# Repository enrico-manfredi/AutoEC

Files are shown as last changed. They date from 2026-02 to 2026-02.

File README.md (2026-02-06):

# AutoEC

**AutoEC** is an open-source **automated pumping and switching system** designed to support **batch electrochemical testing of electrolytes through membrane electrode assemblies (MEAs)**.

The system was developed to enable reproducible, programmable control of fluid handling during electrochemical experiments, particularly where repeated electrolyte exchange, flow control, and test cycling are required.

This repository contains control software, test scripts, mechanical design assets, and documentation describing the AutoEC prototype platform.

---

## Project objectives

- Automate fluid handling for electrochemical testing
- Enable programmable control of pumps and switching sequences
- Improve repeatability and throughput in batch MEA experiments
- Provide a flexible platform for rapid experimental iteration

---

## System overview

AutoEC integrates:

### Control software
- **Python-based host control scripts** for pump actuation and experiment sequencing
- Modular test scripts used to validate hardware functionality
- A high-level control interface for coordinating fluid handling steps

### Pump control
- Syringe pumps are controlled using the open-source **`runze-control` Python library**, developed by **Allen Institute / AllenNeuralDynamics**
- This library provides the low-level serial communication and command abstraction for Runze syringe pumps

### Mechanical system
- CAD parts and assemblies (`.ipt`, `.iam`) supporting:
  - Syringe pump frames and holders
  - Structural frames and chamber fixtures
  - Z-axis bars and mounting components

---

## Dependencies

AutoEC relies on the following external libraries:

### Required
- **runze-control**  
  Pump control library for Runze syringe pumps  
  Developed and maintained by **AllenNeuralDynamics**  
  https://github.com/AllenNeuralDynamics/runze-control

- **pyserial**  
  Required for serial communication with pump hardware

Install dependencies using:
```bash
pip install pyserial
pip install git+https://github.com/AllenNeuralDynamics/runze-control.git

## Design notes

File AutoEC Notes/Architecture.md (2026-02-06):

![[Pasted image 20240330184920.png]]
## Modules
- Mains power is an extension chord with enough plugs for other the [[Power Supplies]] of connected devices (5) and is connected to a [[Kill Switch]] that allows for the system to be switched off automatically (int22) for safety and sustainability reasons.
- The Control PC is a windows machine that centrally controls the movement and operation of all devices in the system, and is also responsible for monitoring errors or failure conditions. Should be accessible remotely.
- [[Syringe Pump]] is the fluid driving element that retrieves both sample and wash solution and pumps them through the electrochemical cell
- Test solutions are solutions of [[Catholyte]] and [[Anolyte]] that need to be tested, and will be in a [[Sample Rack]] which is easily accessible and interchangeable to the user
- [[Wash Solution]] will be used to purge all elements of the fluid system from any traces of test solutions
- [[Potentiostat]] is the device that controls cell potential and current between the electrodes as well as responsible for taking measurements from the cell and reporting those measurements to the control PC.
- [[Booster]] is a device controlled by the potentiostat via proprietary interface (int13) that increases the amount of current that can be delivered to the cell.
- The [[Cell]] is [[Membrane]] [[Electrode]] assembly (MEA) in which the test solutions travel through a [[Fluid Path]] during electrochemical measurement by the potentiostat.
- Test solution [[Reservoirs]] are chambers where the current test solution will drain into after being pumped through the cell and where the syringe filters will fill from during operation and dispense to when setting up for a new test solution run.
- [[Thermal Control]] is the thermostat system that will heat up the cell and/or syringe pumps and reservoirs to maintain a constant temperature for the liquids being run through the system.

## Interfaces
1. Fluid transfer link between wash solution reservoir and the syringe pump valve selector
2. Fluid transfer link from the syringe pump to a waste container for spent wash solution and/or excess test solutions
3. Fluid transfer link from the test solution reservoir to the syringe pump such that the syringe pump can be loaded with test solution
4. Fluid transfer link from the syringe pump to the test solution reservoir such that the syringe pump can be dispensed into the test solution reservoir (in implementation this would be on the same fluid line as 3 as the syringe pump is bidirectional)
5. A fluid transfer link between the syringe pump and the cell fluid inlet such that the syringe pump can dispense test solution into the cell
6. A fluid transfer link between the cell and the test solution reservoir such that fluid moving through the cell can be drained into the reservoir
7. An electrical communication link from the syringe pump to the control PC shows the control PC the pump status and any errors that the pump has encountered, such as overheating, stalling or blockage
8. An electrical communication link from the control PC to the syringe pump that allows the control PC to send actuation commands to the syringe pump (in implementation this will be a single bidirectional RS-485 connection using the protocol set out in [[Syringe Pump]])
9. A fluid transfer link from a particular test solution in the test solution rack to the syringe pump that allows for test solution to be drawn into the syringe pump
10. A fluid transfer link from the syringe pump to a particular test solution in the test solution rack that allows for the dispensation of test solution from the syringe pump into the appropriate sample container

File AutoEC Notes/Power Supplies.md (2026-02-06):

Control PC, Potentiostat and Thermal control all come with their own mains power supplies.

[[Syringe Pump]] will have their own integrated supply composed of one 24V 10A mains power brick to fit with other elements of the system

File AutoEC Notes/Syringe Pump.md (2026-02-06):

A integrated syringe pump and 6-way selector valve. Usage instructions are provided in the manual below:
[[sy-01b-ascii-code-instruction-manuall-v1-1.pdf]]
## General
- The stepper motor controlling the syringe stroke has 12,000 steps total 
- stroke length of 30mm
- Can take syringes from 25uL to 5mL
- All numbers sent via serial (for example for number of steps) must be sent in hexadecimal
- Recommends using RS232/485 comm protocol as it will send back more checksum and status data than raw terminal commands
- Requires 24V power with minimum 1.5A specification and a maximum operating current of 31A (and limit of 35A)
- Must always be run with liquid else the sealing surfaces can be damaged
- Have a self test mode if address switch is set to position F
## Addressing
![[Pasted image 20240330162039.png]]

## Comm Protocol
![[Pasted image 20240330161352.png]]
For sending data:
- STX is the start string
- Pump address is according to the table in [[Syringe Pump#Addressing]]
- Sequence number -  a number from 0-7 and a bit flag for repetition. Only read if the bit flag is high - used to check whether it is currently repeating the same command as previous or whether (acknowledge only) it is receiving a new command to repeat (acknowledge and execute).
- Data block - the data or command to be sent as an ascii string (see [[Syringe Pump#Commands]])
- ETX is the end of the string
- Checksum is used to check for communication errors or corruptions

For receiving data:
- Master address - the address of the host computer - always set to 30h (0 in ascii)
- Status code - a code that will either indicate pump status (ready/busy) or [[Syringe Pump#Error Codes]]

## Manual Control
Using SerialCommV1.0 provided by Runze it is possible to operate a single pump directly from the terminal by sending and receiving serial commands. This software only works with windows.
Other settings:
- Only 9600 Brate supported (other params same as [[Syringe Pump#Comm Protocol]])
- Pump address switch must be set to 0.
## Commands
### General
Commands are stored in a 255 char buffer. A single R at the end of the command string indicates that the command is to be run immediately, otherwise it will enter the buffer and be kept there until a new command is received where the buffer will be overwritten. The pump will not accept further commands unless the current command has been completed (hence don't send until confirmation of complete command from the pump - can maybe also place in buffer?). If the command receives an incorrect command it will send an error code back to the host computer.

#### Backlash Config
Kn where n is between 0-800 for full steps and 0-1600 in microstepping mode (fine positioning which does halg steps)

#### Pump Config
Un where n can take the following values:
![[Pasted image 20240330174535.png]]
The pump must be restarted for these to take effect.

The U200 commands are presumably in the form of U201 for a 1A stall current and U231 for a 31A stall current (to be tested)
- Stall current must be set to be below the maximum rated current of the power supply being used

#### Initialisation
The plunger and valve drive can be initialised seperately or together and going counter clockwise Y(n1, n2, n3) or clockwise Z(n1, n2, n3) - presumably the sub blocks use commas as separators

For combined plunger and valve initialisation, the table of values is shown below:
![[Pasted image 20240330175514.png]]
## Error Codes

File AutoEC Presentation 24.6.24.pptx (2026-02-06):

## Current Setup

Wash

Waste

Control PC

Wash

Waste

3

4

Anode Samples

Potentiostat

1

2

Anode
Pumps

Temp
Control

Cathode
Pumps

Anolyte
Chamber

Catholyte
Chamber

Cathode Samples

## Current Spec

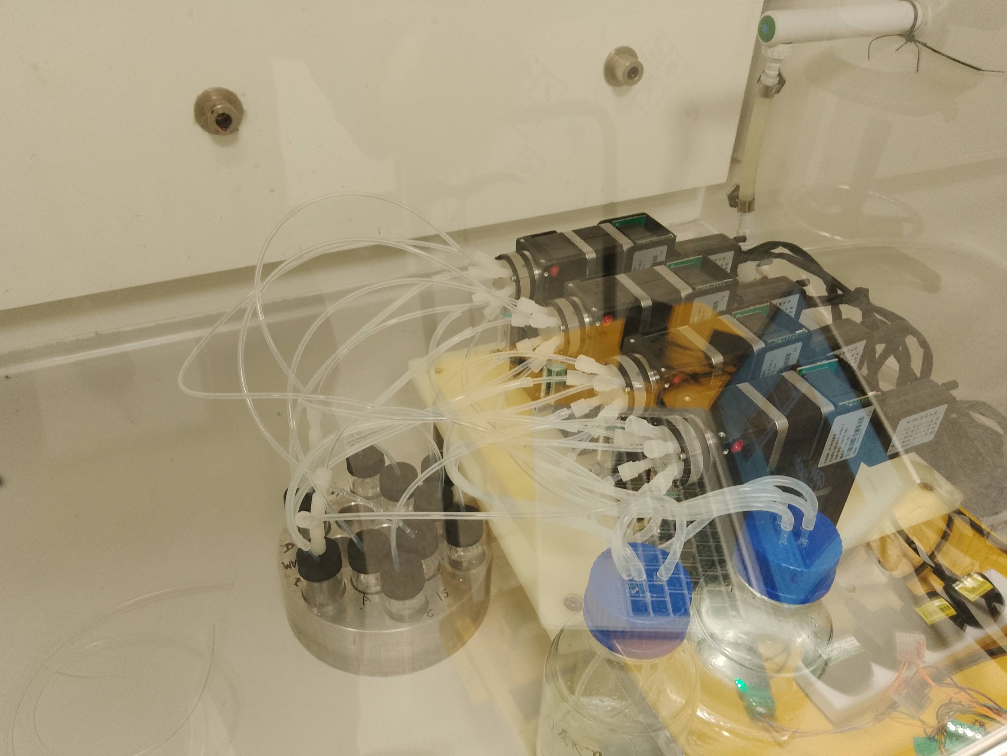
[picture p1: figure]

- Addressable samples for each run
  - E.g. [1,2] means 1st sample on anode and 2nd sample on cathode
  - Returns samples to original pot after testing (15ml)
- System runs on ivium potentiostat
  - Runs off saved methods from ivsoft
- Cleaning functions integrated at the end of every run
  - Membrane
  - Chamber
  - Syringes
- Manual temperature control – all experiments in one batch (4 pairs) must be run at one temp
- Currently based in Chem831 for prototyping & testing

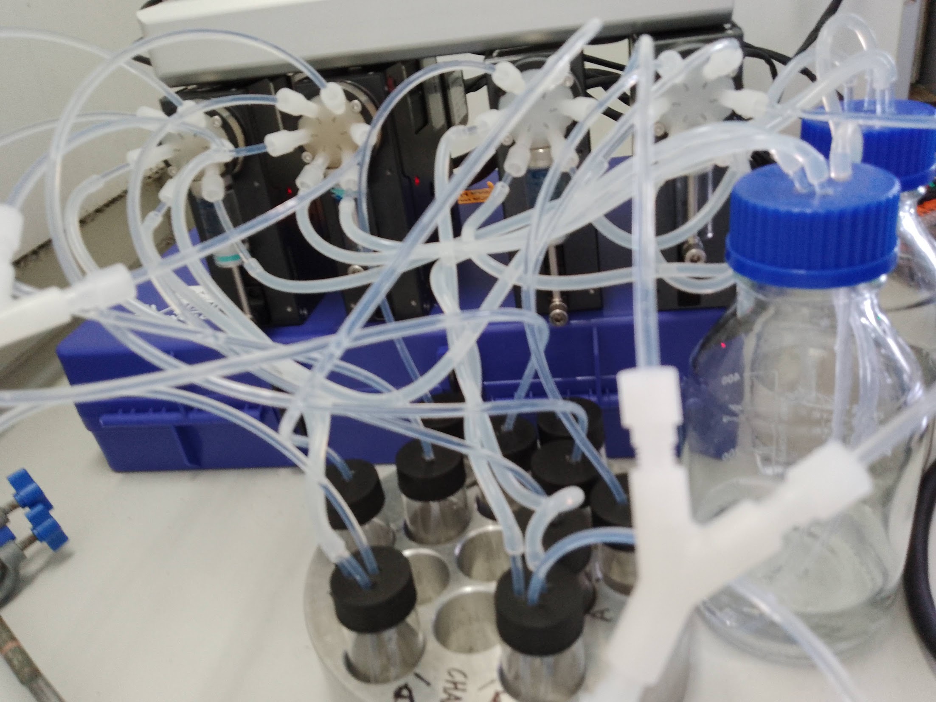
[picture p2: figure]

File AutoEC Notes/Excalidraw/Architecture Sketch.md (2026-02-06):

---

excalidraw-plugin: parsed
tags: [excalidraw]

---
==⚠  Switch to EXCALIDRAW VIEW in the MORE OPTIONS menu of this document. ⚠==

# Text Elements
Cell ^l1ibORYI

Test Solution Reservoirs ^jnntJJiP

Potentiostat ^KO1CpPYg

Booster ^whiRIF5I

Syringe Pump ^FSPLhmo9

Test Solutions ^VonvnywQ

Control PC ^r2QTvRRM

Wash Solution ^82Awlkmj

1 ^7IcscnHT

2 ^HzHET0HD

3 ^dt2o3Fhl

4 ^zDjwsGoj

5 ^eu0UEI3d

6 ^kACNqNml

7 ^nSBoxbeC

8 ^qrnZnVmD

9 ^oPMFp0x9

10 ^uov3VFLc

11 ^4vQkV3Ot

12 ^VfAVOvvz

13 ^rdQFTPa8

14 ^UYDHrkcZ

15 ^f7A9KPbZ

Thermal Control ^VKspB7Ql

16 ^eN7tv0N0

24 ^S0jkShm5

25 ^kDEbEBqd

19 ^sT7MlVia

17 ^4mHRUdfI

Mains Power ^oH1eUweU

18 ^sdlnf21B

19 ^9JnUwH7v

20 ^PlxXwrGl

21 ^o0szQ5ke

22 ^zDNTCGsT

23 ^8Dt4diBY

%%
# Drawing
```json
{
	"type": "excalidraw",
	"version": 2,
	"source": "https://github.com/zsviczian/obsidian-excalidraw-plugin/releases/tag/2.0.26",
	"elements": [
		{
			"type": "rectangle",
			"version": 182,
			"versionNonce": 1813121673,
			"isDeleted": false,
			"id": "bU9Jms2O_zU1_lSFDH0oY",
			"fillStyle": "solid",
			"strokeWidth": 2,
			"strokeStyle": "solid",
			"roughness": 1,
			"opacity": 100,
			"angle": 0,
			"x": -9.6666259765625,
			"y": -386.7864532470703,
			"strokeColor": "#1e1e1e",
			"backgroundColor": "transparent",
			"width": 86.666748046875,
			"height": 57.3333740234375,
			"seed": 99178377,
			"groupIds": [],
			"frameId": null,
			"roundness": {
				"type": 3
			},
			"boundElements": [
				{
					"type": "text",
					"id": "l1ibORYI"
				},
				{
					"id": "BvJilRcO0jTmNDnqUFmX5",
					"type": "arrow"
				},
				{
					"id": "ODdBEutdLjqXaOnD44ZyQ",
					"type": "arrow"
				},
				{
					"id": "G5-fBYSrN0bbWU4KgB2QC",
					"type": "arrow"
				},
				{
					"id": "1mDEJUfH4Xlski9YfvWLL",
					"type": "arrow"
				},
				{
					"id": "Q9TIKDFtSWsWlMSElXdRT",
					"type": "arrow"
				}
			],
			"updated": 1711823752772,
			"link": null,
			"locked": false
		},
		{
			"type": "text",
			"version": 159,
			"versionNonce": 1463967209,
			"isDeleted": false,
			"id": "l1ibORYI",
			"fillStyle": "solid",
			"strokeWidth": 2,
			"strokeStyle": "solid",
			"roughness": 1,
			"opacity": 100,
			"angle": 0,
			"x": 16.49676513671875,
			"y": -370.61976623535156,
			"strokeColor": "#1e1e1e",
			"backgroundColor": "transparent",
			"width": 34.3399658203125,
			"height": 25,
			"seed": 1843980713,
			"groupIds": [],
			"frameId": null,
			"roundness": null,
			"boundElements": [],
			"updated": 1711823525700,
			"link": null,
			"locked": false,
			"fontSize": 20,
			"fontFamily": 1,
			"text": "Cell",
			"rawText": "Cell",
			"textAlign": "center",
			"verticalAlign": "middle",
			"containerId": "bU9Jms2O_zU1_lSFDH0oY",
			"originalText": "Cell",
			"lineHeight": 1.25
		},
		{
			"type": "rectangle",
			"version": 694,
			"versionNonce": 569758023,
			"isDeleted": false,
			"id": "ODWRP1MtLcp3Vh7PsQYtS",
			"fillStyle": "solid",
			"strokeWidth": 2,
			"strokeStyle": "solid",
			"roughness": 1,
			"opacity": 100,
			"angle": 0,
			"x": -50.66680908203125,
			"y": -570.7864990234375,
			"strokeColor": "#1e1e1e",
			"backgroundColor": "transparent",
			"width": 162.00006103515622,
			"height": 71,
			"seed": 1713174183,
			"groupIds": [],
			"frameId": null,
			"roundness": {
				"type": 3
			},
			"boundElements": [
				{
					"type": "text",
					"id": "jnntJJiP"
				},
				{
					"id": "bC6mpMbLD5vmOgMO0ALFV",
					"type": "arrow"
				},
				{
					"id": "BvJilRcO0jTmNDnqUFmX5",
					"type": "arrow"
				},
				{
					"id": "ODdBEutdLjqXaOnD44ZyQ",
					"type": "arrow"
				},
				{
					"id": "aO0yKPbcSyfrLUch1YeXE",
					"type": "arrow"
				},
				{
					"id": "nsKn9Tmc4jUIkaFDwNtvG",
					"type": "arrow"
				}
			],
			"updated": 1711823757336,
			"link": null,
			"locked": false
		},
		{
			"type": "text",
			"version": 708,
			"versionNonce": 1259805481,
			"isDeleted": false,
			"id": "jnntJJiP",
			"fillStyle": "solid",
			"strokeWidth": 2,
			"strokeStyle": "solid",
			"roughness": 1,
			"opacity": 100,
			"angle": 0,
			"x": -37.23670959472658,
			"y": -560.2864990234375,
			"strokeColor": "#1e1e1e",
			"backgroundColor": "transparent",
			"width": 135.13986206054688,
			"height": 50,
			"seed": 1555401159,
			"groupIds": [],
			"frameId": null,
			"roundness": null,
			"boundElements": [],
			"updated": 1711823525700,
			"link": null,
			"locked": false,
			"fontSize": 20,
			"fontFamily": 1,
			"text": "Test Solution\nReservoirs",
			"rawText": "Test Solution Reservoirs",
			"textAlign": "center",
			"verticalAlign": "middle",
			"containerId": "ODWRP1MtLcp3Vh7PsQYtS",
			"originalText": "Test Solution Reservoirs",
			"lineHeight": 1.25
		},
		{
			"type": "rectangle",
			"version": 263,
			"versionNonce": 107527369,
			"isDeleted": false,
			"id": "3vFeRiSeK2OI2f1WuSYI6",
			"fillStyle": "solid",
			"strokeWidth": 2,
			"strokeStyle": "solid",
			"roughness": 1,
			"opacity": 100,
			"angle": 0,
			"x": 19.00006103515625,
			"y": -128.7863311767578,
			"strokeColor": "#1e1e1e",
			"backgroundColor": "transparent",
			"width": 147.99993896484375,
			"height": 64.00000000000001,
			"seed": 596154183,
			"groupIds": [],
			"frameId": null,
			"roundness": {
				"type": 3
			},
			"boundElements": [
				{
					"type": "text",
					"id": "KO1CpPYg"
				},
				{
					"id": "vgSNt6wNqVpfVCbIR9f1w",
					"type": "arrow"
				},
				{
					"id": "1mDEJUfH4Xlski9YfvWLL",
					"type": "arrow"
				},
				{
					"id": "WnmydR_rrgiI1EIDTvmJa",
					"type": "arrow"
				},
				{
					"id": "8TptVns8V0LvRrpCr_jtZ",
					"type": "arrow"
				},
				{
					"id": "TLeKdNhl8hJ3KNtLr0rVx",
					"type": "arrow"
				}
			],
			"updated": 1711824281116,
			"link": null,
			"locked": false
		},
		{
			"type": "text",
			"version": 239,
			"versionNonce": 1947002985,
			"isDeleted": false,
			"id": "KO1CpPYg",
			"fillStyle": "solid",
			"strokeWidth": 2,
			"strokeStyle": "solid",
			"roughness": 1,
			"opacity": 100,
			"angle": 0,
			"x": 28.28009796142578,
			"y": -109.28633117675781,
			"strokeColor": "#1e1e1e",
			"backgroundColor": "transparent",
			"width": 129.4398651123047,
			"height": 25,
			"seed": 373793639,
			"groupIds": [],
			"frameId": null,
			"roundness": null,
			"boundElements": [],
			"updated": 1711823525700,
			"link": null,
			"locked": false,
			"fontSize": 20,
			"fontFamily": 1,
			"text": "Potentiostat",
			"rawText": "Potentiostat",
			"textAlign": "center",
			"verticalAlign": "middle",
			"containerId": "3vFeRiSeK2OI2f1WuSYI6",
			"originalText": "Potentiostat",
			"lineHeight": 1.25
		},
		{
			"type": "rectangle",
			"version": 424,
			"versionNonce": 1791202121,
			"isDeleted": false,
			"id": "dKkvgd4W00acrC5qZFvRn",
			"fillStyle": "solid",
			"strokeWidth": 2,
			"strokeStyle": "solid",
			"roughness": 1,
			"opacity": 100,
			"angle": 0,
			"x": 17.333343505859375,
			"y": -251.4530792236328,
			"strokeColor": "#1e1e1e",
			"backgroundColor": "transparent",
			"width": 115.333251953125,
			"height": 50.666687011718736,
			"seed": 936432327,
			"groupIds": [],
			"frameId": null,
			"roundness": {
				"type": 3
			},
			"boundElements": [
				{
					"type": "text",
					"id": "whiRIF5I"
				},
				{
					"id": "G5-fBYSrN0bbWU4KgB2QC",
					"type": "arrow"
				},
				{
					"id": "vgSNt6wNqVpfVCbIR9f1w",
					"type": "arrow"
				},
				{
					"id": "cscG2V1hwLWiyM6O2XQi9",
					"type": "arrow"
				}
			],
			"updated": 1711824287372,
			"link": null,
			"locked": false
		},
		{
			"type": "text",
			"version": 409,
			"versionNonce": 1779942825,
			"isDeleted": false,
			"id": "whiRIF5I",
			"fillStyle": "solid",
			"strokeWidth": 2,
			"strokeStyle": "solid",
			"roughness": 1,
			"opacity": 100,
			"angle": 0,
			"x": 35.800010681152344,
			"y": -238.61973571777344,
			"strokeColor": "#1e1e1e",
			"backgroundColor": "transparent",
			"width": 78.39991760253906,
			"height": 25,
			"seed": 1608049127,
			"groupIds": [],
			"frameId": null,
			"roundness": null,
			"boundElements": [],
			"updated": 1711823525700,
			"link": null,
			"locked": false,
			"fontSize": 20,
			"fontFamily": 1,
			"text": "Booster",
			"rawText": "Booster",
			"textAlign": "center",
			"verticalAlign": "middle",
			"containerId": "dKkvgd4W00acrC5qZFvRn",
			"originalText": "Booster",
			"lineHeight": 1.25
		},
		{
			"type": "rectangle",
			"version": 522,
			"versionNonce": 1964805415,
			"isDeleted": false,
			"id": "0TH1Q8r3-1oxOPPtuFwd4",
			"fillStyle": "solid",
			"strokeWidth": 2,
			"strokeStyle": "solid",
			"roughness": 1,
			"opacity": 100,
			"angle": 0,
			"x": -185.99993896484375,
			"y": -399.11985778808594,
			"strokeColor": "#1e1e1e",
			"backgroundColor": "transparent",
			"width": 102.6666259765625,
			"height": 60,
			"seed": 1482070887,
			"groupIds": [],
			"frameId": null,
			"roundness": {
				"type": 3
			},
			"boundElements": [
				{
					"type": "text",
					"id": "FSPLhmo9"
				},
				{
					"id": "enI0Gv2CJua86-YhZFvDU",
					"type": "arrow"
				},
				{
					"id": "bC6mpMbLD5vmOgMO0ALFV",
					"type": "arrow"
				},
				{
					"id": "DohW-taXoE-uIEI_2FnnT",
					"type": "arrow"
				},
				{
					"id": "wcmA01sqSDBKsLx3GLCXA",
					"type": "arrow"
				},
				{
					"id": "poeBGR7nkOoXHoHTLJWXH",
					"type": "arrow"
				},
				{
					"id": "aO0yKPbcSyfrLUch1YeXE",
					"type": "arrow"
				},
				{
					"id": "uCttJyokoXdWlUvNB0RQG",
					"type": "arrow"
				},
				{
					"id": "5Zj_0U34enpYEs7bhw5o1",
					"type": "arrow"
				},
				{
					"id": "YjDV_4WW3z9hB24ijSn9G",
					"type": "arrow"
				},
				{
					"id": "GrVChs8RONhCqfv4I8e7B",
					"type": "arrow"
				},
				{
					"id": "BvJilRcO0jTmNDnqUFmX5",
					"type": "arrow"
				}
			],
			"updated": 1712074583495,
			"link": null,
			"locked": false
		},
		{
			"type": "text",
			"version": 484,
			"versionNonce": 208087337,
			"isDeleted": false,
			"id": "FSPLhmo9",
			"fillStyle": "solid",
			"strokeWidth": 2,
			"strokeStyle": "solid",
			"roughness": 1,
			"opacity": 100,
			"angle": 0,
			"x": -167.07659149169922,
			"y": -394.11985778808594,
			"strokeColor": "#1e1e1e",
			"backgroundColor": "transparent",
			"width": 64.81993103027344,
			"height": 50,
			"seed": 1239193223,
			"groupIds": [],
			"frameId": null,
			"roundness": null,
			"boundElements": [],
			"updated": 1711823525700,
			"link": null,
			"locked": false,
			"fontSize": 20,
			"fontFamily": 1,
			"text": "Syringe\nPump",
			"rawText": "Syringe Pump",
			"textAlign": "center",
			"verticalAlign": "middle",
			"containerId": "0TH1Q8r3-1oxOPPtuFwd4",
			"originalText": "Syringe Pump",
			"lineHeight": 1.25
		},
		{
			"type": "rectangle",
			"version": 726,
			"versionNonce": 1527309607,
			"isDeleted": false,
			"id": "JYXKch51sxRrdpWpH71tc",
			"fillStyle": "solid",
			"strokeWidth": 2,
			"strokeStyle": "solid",
			"roughness": 1,
			"opacity": 100,
			"angle": 0,
			"x": -191.2701497085289,
			"y": -217.37008729779745,
			"strokeColor": "#1e1e1e",
			"backgroundColor": "transparent",
			"width": 102.6666259765625,
			"height": 60,
			"seed": 1685218025,
			"groupIds": [],
			"frameId": null,
			"roundness": {
				"type": 3
			},
			"boundElements": [
				{
					"type": "text",
					"id": "VonvnywQ"
				},
				{
					"id": "enI0Gv2CJua86-YhZFvDU",
					"type": "arrow"
				},
				{
					"id": "DohW-taXoE-uIEI_2FnnT",
					"type": "arrow"
				}
			],
			"updated": 1711824239220,
			"link": null,
			"locked": false
		},
		{
			"type": "text",
			"version": 720,
			"versionNonce": 1528801351,
			"isDeleted": false,
			"id": "VonvnywQ",
			"fillStyle": "solid",
			"strokeWidth": 2,
			"strokeStyle": "solid",
			"roughness": 1,
			"opacity": 100,
			"angle": 0,
			"x": -183.3467869765953,
			"y": -212.37008729779745,
			"strokeColor": "#1e1e1e",
			"backgroundColor": "transparent",
			"width": 86.81990051269531,
			"height": 50,
			"seed": 332930505,
			"groupIds": [],
			"frameId": null,
			"roundness": null,
			"boundElements": [],
			"updated": 1711824239220,
			"link": null,
			"locked": false,
			"fontSize": 20,
			"fontFamily": 1,
			"text": "Test\nSolutions",
			"rawText": "Test Solutions",
			"textAlign": "center",
			"verticalAlign": "middle",
			"containerId": "JYXKch51sxRrdpWpH71tc",
			"originalText": "Test Solutions",
			"lineHeight": 1.25
		},
		{
			"type": "arrow",
			"version": 692,
			"versionNonce": 1043069351,
			"isDeleted": false,
			"id": "enI0Gv2CJua86-YhZFvDU",
			"fillStyle": "solid",
			"strokeWidth": 2,
			"strokeStyle": "solid",
			"roughness": 1,
			"opacity": 100,
			"angle": 0,
			"x": -173.57272661146584,
			"y": -229.70346132123495,
			"strokeColor": "#1e1e1e",
			"backgroundColor": "transparent",
			"width": 2.8383024337055645,
			"height": 96.41636594927286,
			"seed": 1249848263,
			"groupIds": [],
			"frameId": null,
			"roundness": {
				"type": 2
			},
			"boundElements": [
				{
					"type": "text",
					"id": "oPMFp0x9"
				}
			],
			"updated": 1712073796478,
			"link": null,
			"locked": false,
			"startBinding": {
				"elementId": "JYXKch51sxRrdpWpH71tc",
				"gap": 12.3333740234375,
				"focus": -0.6680288907144092
			},
			"endBinding": {
				"elementId": "0TH1Q8r3-1oxOPPtuFwd4",
				"gap": 13.000030517578125,
				"focus": 0.6664942364970273
			},
			"lastCommittedPoint": null,
			"startArrowhead": null,
			"endArrowhead": "arrow",
			"points": [
				[
					0,
					0
				],
				[
					2.8383024337055645,
					-96.41636594927286
				]
			]
		},
		{
			"type": "text",
			"version": 2,
			"versionNonce": 2005278887,
			"isDeleted": false,
			"id": "oPMFp0x9",
			"fillStyle": "solid",
			"strokeWidth": 2,
			"strokeStyle": "solid",
			"roughness": 1,
			"opacity": 100,
			"angle": 0,
			"x": -183.53589980463613,
			"y": 102.71350097656251,
			"strokeColor": "#1e1e1e",
			"backgroundColor": "transparent",
			"width": 12.17999267578125,
			"height": 25,
			"seed": 6941865,
			"groupIds": [],
			"frameId": null,
			"roundness": null,
			"boundElements": [],
			"updated": 1711823453330,
			"link": null,
			"locked": false,
			"fontSize": 20,
			"fontFamily": 1,
			"text": "9",
			"rawText": "9",
			"textAlign": "center",
			"verticalAlign": "middle",
			"containerId": "enI0Gv2CJua86-YhZFvDU",
			"originalText": "9",
			"lineHeight": 1.25
		},
		{
			"type": "arrow",
			"version": 325,
			"versionNonce": 250289191,
			"isDeleted": false,
			"id": "bC6mpMbLD5vmOgMO0ALFV",
			"fillStyle": "solid",
			"strokeWidth": 2,
			"strokeStyle": "solid",
			"roughness": 1,
			"opacity": 100,
			"angle": 0,
			"x": -79,
			"y": -386.68933894139536,
			"strokeColor": "#1e1e1e",
			"backgroundColor": "transparent",
			"width": 71.34436332718883,
			"height": 108.7638013173937,
			"seed": 1119397577,
			"groupIds": [],
			"frameId": null,
			"roundness": {
				"type": 2
			},
			"boundElements": [
				{
					"type": "text",
					"id": "zDjwsGoj"
				}
			],
			"updated": 1712073796467,
			"link": null,
			"locked": false,
			"startBinding": {
				"elementId": "0TH1Q8r3-1oxOPPtuFwd4",
				"gap": 4.33331298828125,
				"focus": 0.6216103198222338
			},
			"endBinding": {
				"elementId": "ODWRP1MtLcp3Vh7PsQYtS",
				"gap": 4.3333587646484375,
				"focus": 0.11372414050710765
			},
			"lastCommittedPoint": null,
			"startArrowhead": null,
			"endArrowhead": "arrow",
			"points": [
				[
					0,
					0
				],
				[
					71.34436332718883,
					-108.7638013173937
				]
			]
		},
		{
			"type": "text",
			"version": 2,
			"versionNonce": 680751625,
			"isDeleted": false,
			"id": "zDjwsGoj",
			"fillStyle": "solid",
			"strokeWidth": 2,
			"strokeStyle": "solid",
			"roughness": 1,
			"opacity": 100,
			"angle": 0,
			"x": -65.066650390625,
			"y": -42.28643798828125,
			"strokeColor": "#1e1e1e",
			"backgroundColor": "transparent",
			"width": 12.79998779296875,
			"height": 25,
			"seed": 1821335975,
			"groupIds": [],
			"frameId": null,
			"roundness": null,
			"boundElements": [],
			"updated": 1711823440082,
			"link": null,
			"locked": false,
			"fontSize": 20,
			"fontFamily": 1,
			"text": "4",
			"rawText": "4",
			"textAlign": "center",
			"verticalAlign": "middle",
			"containerId": "bC6mpMbLD5vmOgMO0ALFV",
			"originalText": "4",
			"lineHeight": 1.25
		},
		{
			"type": "arrow",
			"version": 371,
			"versionNonce": 920631913,
			"isDeleted": false,
			"id": "BvJilRcO0jTmNDnqUFmX5",
			"fillStyle": "solid",
			"strokeWidth": 2,
			"strokeStyle": "solid",
			"roughness": 1,
			"opacity": 100,
			"angle": 0,
			"x": -69.93173817703388,
			"y": -366.5007680257161,
			"strokeColor": "#1e1e1e",
			"backgroundColor": "transparent",
			"width": 51.52073542804675,
			"height": 0.95233154296875,
			"seed": 1057419879,
			"groupIds": [],
			"frameId": null,
			"roundness": {
				"type": 2
			},
			"boundElements": [
				{
					"type": "text",
					"id": "eu0UEI3d"
				}
			],
			"updated": 1712074588780,
			"link": null,
			"locked": false,
			"startBinding": {
				"elementId": "0TH1Q8r3-1oxOPPtuFwd4",
				"focus": 0.12328972790855727,
				"gap": 13.401574811247372
			},
			"endBinding": {
				"elementId": "bU9Jms2O_zU1_lSFDH0oY",
				"focus": 0.34939842734033033,
				"gap": 8.74437677242463
			},
			"lastCommittedPoint": null,
			"startArrowhead": null,
			"endArrowhead": "arrow",
			"points": [
				[
					0,
					0
				],
				[
					51.52073542804675,
					-0.95233154296875
				]
			]
		},
		{
			"type": "text",
			"version": 2,
			"versionNonce": 290571655,
			"isDeleted": false,
			"id": "eu0UEI3d",
			"fillStyle": "solid",
			"strokeWidth": 2,
			"strokeStyle": "solid",
			"roughness": 1,
			"opacity": 100,
			"angle": 0,
			"x": 15.077347798708225,
			"y": -67.95309448242188,
			"strokeColor": "#1e1e1e",
			"backgroundColor": "transparent",
			"width": 12.3599853515625,
			"height": 25,
			"seed": 1529541065,
			"groupIds": [],
			"frameId": null,
			"roundness": null,
			"boundElements": [],
			"updated": 1711823444481,
			"link": null,
			"locked": false,
			"fontSize": 20,
			"fontFamily": 1,
			"text": "5",
			"rawText": "5",
			"textAlign": "center",
			"verticalAlign": "middle",
			"containerId": "BvJilRcO0jTmNDnqUFmX5",
			"originalText": "5",
			"lineHeight": 1.25
		},
		{
			"type": "arrow",
			"version": 335,
			"versionNonce": 1528283911,
			"isDeleted": false,
			"id": "ODdBEutdLjqXaOnD44ZyQ",
			"fillStyle": "solid",
			"strokeWidth": 2,
			"strokeStyle": "solid",
			"roughness": 1,
			"opacity": 100,
			"angle": 0,
			"x": 67.37237305726514,
			"y": -388.78645324707037,
			"strokeColor": "#1e1e1e",
			"backgroundColor": "transparent",
			"width": 5.815176727143395,
			"height": 108.6666870117187,
			"seed": 547425001,
			"groupIds": [],
			"frameId": null,
			"roundness": {
				"type": 2
			},
			"boundElements": [
				{
					"type": "text",
					"id": "kACNqNml"
				}
			],
			"updated": 1712073796450,
			"link": null,
			"locked": false,
			"startBinding": {
				"elementId": "bU9Jms2O_zU1_lSFDH0oY",
				"gap": 2,
				"focus": 0.714650345920699
			},
			"endBinding": {
				"elementId": "ODWRP1MtLcp3Vh7PsQYtS",
				"gap": 2.3333587646484375,
				"focus": -0.541363824320227
			},
			"lastCommittedPoint": null,
			"startArrowhead": null,
			"endArrowhead": "arrow",
			"points": [
				[
					0,
					0
				],
				[
					5.815176727143395,
					-108.6666870117187
				]
			]
		},
		{
			"type": "text",
			"version": 2,
			"versionNonce": 1211488457,
			"isDeleted": false,
			"id": "kACNqNml",
			"fillStyle": "solid",
			"strokeWidth": 2,
			"strokeStyle": "solid",
			"roughness": 1,
			"opacity": 100,
			"angle": 0,
			"x": 53.879967524352466,
			"y": -65.61978149414062,
			"strokeColor": "#1e1e1e",
			"backgroundColor": "transparent",
			"width": 12.79998779296875,
			"height": 25,
			"seed": 120962791,
			"groupIds": [],
			"frameId": null,
			"roundness": null,
			"boundElements": [],
			"updated": 1711823446210,
			"link": null,
			"locked": false,
			"fontSize": 20,
			"fontFamily": 1,
			"text": "6",
			"rawText": "6",
			"textAlign": "center",
			"verticalAlign": "middle",
			"containerId": "ODdBEutdLjqXaOnD44ZyQ",
			"originalText": "6",
			"lineHeight": 1.25
		},
		{
			"type": "arrow",
			"version": 450,
			"versionNonce": 1545795143,
			"isDeleted": false,
			"id": "G5-fBYSrN0bbWU4KgB2QC",
			"fillStyle": "solid",
			"strokeWidth": 2,
			"strokeStyle": "solid",
			"roughness": 1,
			"opacity": 100,
			"angle": 0,
			"x": 42.22742426657346,
			"y": -261.4530792236328,
			"strokeColor": "#1e1e1e",
			"backgroundColor": "transparent",
			"width": 43.22742426657346,
			"height": 66.66668701171875,
			"seed": 1093986183,
			"groupIds": [],
			"frameId": null,
			"roundness": {
				"type": 2
			},
			"boundElements": [
				{
					"type": "text",
					"id": "4vQkV3Ot"
				}
			],
			"updated": 1712073796461,
			"link": null,
			"locked": false,
			"startBinding": {
				"elementId": "dKkvgd4W00acrC5qZFvRn",
				"gap": 10,
				"focus": 0.3265849081744923
			},
			"endBinding": {
				"elementId": "bU9Jms2O_zU1_lSFDH0oY",
				"gap": 1.33331298828125,
				"focus": -0.22118340248902257
			},
			"lastCommittedPoint": null,
			"startArrowhead": null,
			"endArrowhead": "arrow",
			"points": [
				[
					0,
					0
				],
				[
					-43.22742426657346,
					-22.66668701171875
				],
				[
					-14.450045253362312,
					-66.66668701171875
				]
			]
		},
		{
			"type": "text",
			"version": 3,
			"versionNonce": 2135237737,
			"isDeleted": false,
			"id": "4vQkV3Ot",
			"fillStyle": "solid",
			"strokeWidth": 2,
			"strokeStyle": "solid",
			"roughness": 1,
			"opacity": 100,
			"angle": 0,
			"x": 9.580001831054688,
			"y": 85.71356201171875,
			"strokeColor": "#1e1e1e",
			"backgroundColor": "transparent",
			"width": 10.839996337890625,
			"height": 25,
			"seed": 2087992871,
			"groupIds": [],
			"frameId": null,
			"roundness": null,
			"boundElements": [],
			"updated": 1711823457074,
			"link": null,
			"locked": false,
			"fontSize": 20,
			"fontFamily": 1,
			"text": "11",
			"rawText": "11",
			"textAlign": "center",
			"verticalAlign": "middle",
			"containerId": "G5-fBYSrN0bbWU4KgB2QC",
			"originalText": "11",
			"lineHeight": 1.25
		},
		{
			"type": "arrow",
			"version": 506,
			"versionNonce": 219845991,
			"isDeleted": false,
			"id": "vgSNt6wNqVpfVCbIR9f1w",
			"fillStyle": "solid",
			"strokeWidth": 2,
			"strokeStyle": "solid",
			"roughness": 1,
			"opacity": 100,
			"angle": 0,
			"x": 73.73661694323559,
			"y": -132.11976623535156,
			"strokeColor": "#1e1e1e",
			"backgroundColor": "transparent",
			"width": 24.73661694323559,
			"height": 67.66662597656256,
			"seed": 820353001,
			"groupIds": [],
			"frameId": null,
			"roundness": {
				"type": 2
			},
			"boundElements": [
				{
					"type": "text",
					"id": "rdQFTPa8"
				}
			],
			"updated": 1712073796462,
			"link": null,
			"locked": false,
			"startBinding": {
				"elementId": "3vFeRiSeK2OI2f1WuSYI6",
				"gap": 3.333435058593743,
				"focus": 0.17716020847881403
			},
			"endBinding": {
				"elementId": "dKkvgd4W00acrC5qZFvRn",
				"gap": 1,
				"focus": 0.11834319517782571
			},
			"lastCommittedPoint": null,
			"startArrowhead": null,
			"endArrowhead": "arrow",
			"points": [
				[
					0,
					0
				],
				[
					-24.73661694323559,
					-22.66668701171875
				],
				[
					-13.127820238199405,
					-67.66662597656256
				]
			]
		},
		{
			"type": "text",
			"version": 3,
			"versionNonce": 890583815,
			"isDeleted": false,
			"id": "rdQFTPa8",
			"fillStyle": "solid",
			"strokeWidth": 2,
			"strokeStyle": "solid",
			"roughness": 1,
			"opacity": 100,
			"angle": 0,
			"x": 49.25291464225104,
			"y": 218.8802490234375,
			"strokeColor": "#1e1e1e",
			"backgroundColor": "transparent",
			"width": 19.039993286132812,
			"height": 25,
			"seed": 1145936233,
			"groupIds": [],
			"frameId": null,
			"roundness": null,
			"boundElements": [],
			"updated": 1711823468274,
			"link": null,
			"locked": false,
			"fontSize": 20,
			"fontFamily": 1,
			"text": "13",
			"rawText": "13",
			"textAlign": "center",
			"verticalAlign": "middle",
			"containerId": "vgSNt6wNqVpfVCbIR9f1w",
			"originalText": "13",
			"lineHeight": 1.25
		},
		{
			"type": "arrow",
			"version": 379,
			"versionNonce": 1959891399,
			"isDeleted": false,
			"id": "1mDEJUfH4Xlski9YfvWLL",
			"fillStyle": "solid",
			"strokeWidth": 2,
			"strokeStyle": "solid",
			"roughness": 1,
			"opacity": 100,
			"angle": 0,
			"x": 81,
			"y": -349.45314025878906,
			"strokeColor": "#1e1e1e",
			"backgroundColor": "transparent",
			"width": 124.66668701171875,
			"height": 226.11503491716758,
			"seed": 1062497031,
			"groupIds": [],
			"frameId": null,
			"roundness": {
				"type": 2
			},
			"boundElements": [
				{
					"type": "text",
					"id": "VfAVOvvz"
				}
			],
			"updated": 1712073796457,
			"link": null,
			"locked": false,
			"startBinding": {
				"elementId": "bU9Jms2O_zU1_lSFDH0oY",
				"gap": 3.9998779296875,
				"focus": -0.5127890409510978
			},
			"endBinding": {
				"elementId": "3vFeRiSeK2OI2f1WuSYI6",
				"gap": 4,
				"focus": 0.828325469160438
			},
			"lastCommittedPoint": null,
			"startArrowhead": null,
			"endArrowhead": "arrow",
			"points": [
				[
					0,
					0
				],
				[
					124.66668701171875,
					116
				],
				[
					90,
					226.11503491716758
				]
			]
		},
		{
			"type": "text",
			"version": 3,
			"versionNonce": 687212903,
			"isDeleted": false,
			"id": "VfAVOvvz",
			"fillStyle": "solid",
			"strokeWidth": 2,
			"strokeStyle": "solid",
			"roughness": 1,
			"opacity": 100,
			"angle": 0,
			"x": 185.8366928100586,
			"y": 144.046875,
			"strokeColor": "#1e1e1e",
			"backgroundColor": "transparent",
			"width": 19.659988403320312,
			"height": 25,
			"seed": 1539846409,
			"groupIds": [],
			"frameId": null,
			"roundness": null,
			"boundElements": [],
			"updated": 1711823458562,
			"link": null,
			"locked": false,
			"fontSize": 20,
			"fontFamily": 1,
			"text": "12",
			"rawText": "12",
			"textAlign": "center",
			"verticalAlign": "middle",
			"containerId": "1mDEJUfH4Xlski9YfvWLL",
			"originalText": "12",
			"lineHeight": 1.25
		},
		{
			"type": "arrow",
			"version": 384,
			"versionNonce": 1098447847,
			"isDeleted": false,
			"id": "DohW-taXoE-uIEI_2FnnT",
			"fillStyle": "solid",
			"strokeWidth": 2,
			"strokeStyle": "solid",
			"roughness": 1,
			"opacity": 100,
			"angle": 0,
			"x": -123.9077776059577,
			"y": -332.11976623535156,
			"strokeColor": "#1e1e1e",
			"backgroundColor": "transparent",
			"width": 0.480593933164414,
			"height": 101.74973997271036,
			"seed": 750968873,
			"groupIds": [],
			"frameId": null,
			"roundness": {
				"type": 2
			},
			"boundElements": [
				{
					"type": "text",
					"id": "uov3VFLc"
				}
			],
			"updated": 1712073796479,
			"link": null,
			"locked": false,
			"startBinding": {
				"elementId": "0TH1Q8r3-1oxOPPtuFwd4",
				"gap": 7.000091552734375,
				"focus": -0.2056160006515632
			},
			"endBinding": {
				"elementId": "JYXKch51sxRrdpWpH71tc",
				"gap": 12.99993896484375,
				"focus": 0.3246770386840179
			},
			"lastCommittedPoint": null,
			"startArrowhead": null,
			"endArrowhead": "arrow",
			"points": [
				[
					0,
					0
				],
				[
					0.480593933164414,
					101.74973997271036
				]
			]
		},
		{
			"type": "text",
			"version": 3,
			"versionNonce": 510917831,
			"isDeleted": false,
			"id": "uov3VFLc",
			"fillStyle": "solid",
			"strokeWidth": 2,
			"strokeStyle": "solid",
			"roughness": 1,
			"opacity": 100,
			"angle": 0,
			"x": -138.46517218429332,
			"y": 99.3802490234375,
			"strokeColor": "#1e1e1e",
			"backgroundColor": "transparent",
			"width": 19.17999267578125,
			"height": 25,
			"seed": 883159977,
			"groupIds": [],
			"frameId": null,
			"roundness": null,
			"boundElements": [],
			"updated": 1711823455250,
			"link": null,
			"locked": false,
			"fontSize": 20,
			"fontFamily": 1,
			"text": "10",
			"rawText": "10",
			"textAlign": "center",
			"verticalAlign": "middle",
			"containerId": "DohW-taXoE-uIEI_2FnnT",
			"originalText": "10",
			"lineHeight": 1.25
		},
		{
			"type": "rectangle",
			"version": 281,
			"versionNonce": 634872103,
			"isDeleted": false,
			"id": "PS8zbXU0lQo1gIlCx1VKb",
			"fillStyle": "solid",
			"strokeWidth": 2,
			"strokeStyle": "solid",
			"roughness": 1,
			"opacity": 100,
			"angle": 0,
			"x": -214.10765646193764,
			"y": 98.45444225175345,
			"strokeColor": "#1e1e1e",
			"backgroundColor": "transparent",
			"width": 120,
			"height": 69.3333740234375,
			"seed": 1677782729,
			"groupIds": [],
			"frameId": null,
			"roundness": {
				"type": 3
			},
			"boundElements": [
				{
					"type": "text",
					"id": "r2QTvRRM"
				},
				{
					"id": "WnmydR_rrgiI1EIDTvmJa",
					"type": "arrow"
				},
				{
					"id": "8TptVns8V0LvRrpCr_jtZ",
					"type": "arrow"
				},
				{
					"id": "wcmA01sqSDBKsLx3GLCXA",
					"type": "arrow"
				},
				{
					"id": "poeBGR7nkOoXHoHTLJWXH",
					"type": "arrow"
				},
				{
					"id": "VVuTYSAhCJ6l3UXlKMnQP",
					"type": "arrow"
				},
				{
					"id": "JQg1EVCmWN3IGGqnq1WWz",
					"type": "arrow"
				},
				{
					"id": "qAOtm6owThPo9_yYwTpe4",
					"type": "arrow"
				},
				{
					"id": "RTg3Z9sVvfRC_algMN-aO",
					"type": "arrow"
				}
			],
			"updated": 1711824268935,
			"link": null,
			"locked": false
		},
		{
			"type": "text",
			"version": 256,
			"versionNonce": 1687213575,
			"isDeleted": false,
			"id": "r2QTvRRM",
			"fillStyle": "solid",
			"strokeWidth": 2,
			"strokeStyle": "solid",
			"roughness": 1,
			"opacity": 100,
			"angle": 0,
			"x": -206.92761038039467,
			"y": 120.6211292634722,
			"strokeColor": "#1e1e1e",
			"backgroundColor": "transparent",
			"width": 105.63990783691406,
			"height": 25,
			"seed": 399771017,
			"groupIds": [],
			"frameId": null,
			"roundness": null,
			"boundElements": [],
			"updated": 1711824183618,
			"link": null,
			"locked": false,
			"fontSize": 20,
			"fontFamily": 1,
			"text": "Control PC",
			"rawText": "Control PC",
			"textAlign": "center",
			"verticalAlign": "middle",
			"containerId": "PS8zbXU0lQo1gIlCx1VKb",
			"originalText": "Control PC",
			"lineHeight": 1.25
		},
		{
			"type": "arrow",
			"version": 759,
			"versionNonce": 283043591,
			"isDeleted": false,
			"id": "WnmydR_rrgiI1EIDTvmJa",
			"fillStyle": "solid",
			"strokeWidth": 2,
			"strokeStyle": "solid",
			"roughness": 1,
			"opacity": 100,
			"angle": 0,
			"x": -91.56917363706371,
			"y": 86.54267242184116,
			"strokeColor": "#1e1e1e",
			"backgroundColor": "transparent",
			"width": 101.2113637603757,
			"height": 160.0464871465331,
			"seed": 1869339017,
			"groupIds": [],
			"frameId": null,
			"roundness": {
				"type": 2
			},
			"boundElements": [
				{
					"type": "text",
					"id": "UYDHrkcZ"
				}
			],
			"updated": 1712073796481,
			"link": null,
			"locked": false,
			"startBinding": {
				"elementId": "PS8zbXU0lQo1gIlCx1VKb",
				"gap": 12.179251025124188,
				"focus": 0.5286802465884888
			},
			"endBinding": {
				"elementId": "3vFeRiSeK2OI2f1WuSYI6",
				"gap": 9.357870911844259,
				"focus": 0.5922809540522336
			},
			"lastCommittedPoint": null,
			"startArrowhead": null,
			"endArrowhead": "arrow",
			"points": [
				[
					0,
					0
				],
				[
					50.021467579230816,
					-105.35176920637531
				],
				[
					101.2113637603757,
					-160.0464871465331
				]
			]
		},
		{
			"type": "text",
			"version": 3,
			"versionNonce": 617298377,
			"isDeleted": false,
			"id": "UYDHrkcZ",
			"fillStyle": "solid",
			"strokeWidth": 2,
			"strokeStyle": "solid",
			"roughness": 1,
			"opacity": 100,
			"angle": 0,
			"x": -39.7888674017229,
			"y": 335.23778215688503,
			"strokeColor": "#1e1e1e",
			"backgroundColor": "transparent",
			"width": 18.219985961914062,
			"height": 25,
			"seed": 314703559,
			"groupIds": [],
			"frameId": null,
			"roundness": null,
			"boundElements": [],
			"updated": 1711823479810,
			"link": null,
			"locked": false,
			"fontSize": 20,
			"fontFamily": 1,
			"text": "14",
			"rawText": "14",
			"textAlign": "center",
			"verticalAlign": "middle",
			"containerId": "WnmydR_rrgiI1EIDTvmJa",
			"originalText": "14",
			"lineHeight": 1.25
		},
		{
			"type": "arrow",
			"version": 596,
			"versionNonce": 1318743591,
			"isDeleted": false,
			"id": "8TptVns8V0LvRrpCr_jtZ",
			"fillStyle": "solid",
			"strokeWidth": 2,
			"strokeStyle": "solid",
			"roughness": 1,
			"opacity": 100,
			"angle": 0,
			"x": 71.60393210851629,
			"y": -58.11976623535156,
			"strokeColor": "#1e1e1e",
			"backgroundColor": "transparent",
			"width": 149.4329419174157,
			"height": 174.0292207193295,
			"seed": 86024263,
			"groupIds": [],
			"frameId": null,
			"roundness": {
				"type": 2
			},
			"boundElements": [
				{
					"type": "text",
					"id": "f7A9KPbZ"
				}
			],
			"updated": 1712073796482,
			"link": null,
			"locked": false,
			"startBinding": {
				"elementId": "3vFeRiSeK2OI2f1WuSYI6",
				"gap": 6.666564941406243,
				"focus": -0.21689181696093054
			},
			"endBinding": {
				"elementId": "PS8zbXU0lQo1gIlCx1VKb",
				"gap": 16.278646653038237,
				"focus": 0.7519217024952412
			},
			"lastCommittedPoint": null,
			"startArrowhead": null,
			"endArrowhead": "arrow",
			"points": [
				[
					0,
					0
				],
				[
					-61.85798610118906,
					52.40889827334149
				],
				[
					-149.4329419174157,
					174.0292207193295
				]
			]
		},
		{
			"type": "text",
			"version": 5,
			"versionNonce": 1939474793,
			"isDeleted": false,
			"id": "f7A9KPbZ",
			"fillStyle": "solid",
			"strokeWidth": 2,
			"strokeStyle": "solid",
			"roughness": 1,
			"opacity": 100,
			"angle": 0,
			"x": -9.25468220013638,
			"y": 343.6319849824918,
			"strokeColor": "#1e1e1e",
			"backgroundColor": "transparent",
			"width": 17.779983520507812,
			"height": 25,
			"seed": 1551562471,
			"groupIds": [],
			"frameId": null,
			"roundness": null,
			"boundElements": [],
			"updated": 1711823483506,
			"link": null,
			"locked": false,
			"fontSize": 20,
			"fontFamily": 1,
			"text": "15",
			"rawText": "15",
			"textAlign": "center",
			"verticalAlign": "middle",
			"containerId": "8TptVns8V0LvRrpCr_jtZ",
			"originalText": "15",
			"lineHeight": 1.25
		},
		{
			"type": "arrow",
			"version": 536,
			"versionNonce": 1436029255,
			"isDeleted": false,
			"id": "wcmA01sqSDBKsLx3GLCXA",
			"fillStyle": "solid",
			"strokeWidth": 2,
			"strokeStyle": "solid",
			"roughness": 1,
			"opacity": 100,
			"angle": 0,
			"x": -193.81514992882518,
			"y": 83.36011612362975,
			"strokeColor": "#1e1e1e",
			"backgroundColor": "transparent",
			"width": 39.333343505859375,
			"height": 445.4798823589813,
			"seed": 1136131049,
			"groupIds": [],
			"frameId": null,
			"roundness": {
				"type": 2
			},
			"boundElements": [
				{
					"type": "text",
					"id": "qrnZnVmD"
				}
			],
			"updated": 1712073796483,
			"link": null,
			"locked": false,
			"startBinding": {
				"elementId": "PS8zbXU0lQo1gIlCx1VKb",
				"gap": 15.094326128123697,
				"focus": -0.5259248922469525
			},
			"endBinding": {
				"elementId": "0TH1Q8r3-1oxOPPtuFwd4",
				"gap": 5.666748046875,
				"focus": 0.9152912012426635
			},
			"lastCommittedPoint": null,
			"startArrowhead": null,
			"endArrowhead": "arrow",
			"points": [
				[
					0,
					0
				],
				[
					-37.18488058875295,
					-310.14656937070004
				],
				[
					2.1484629171064284,
					-445.4798823589813
				]
			]
		},
		{
			"type": "text",
			"version": 2,
			"versionNonce": 1703323337,
			"isDeleted": false,
			"id": "qrnZnVmD",
			"fillStyle": "solid",
			"strokeWidth": 2,
			"strokeStyle": "solid",
			"roughness": 1,
			"opacity": 100,
			"angle": 0,
			"x": -248.6500244140625,
			"y": 150.71356201171875,
			"strokeColor": "#1e1e1e",
			"backgroundColor": "transparent",
			"width": 15.29998779296875,
			"height": 25,
			"seed": 1810338023,
			"groupIds": [],
			"frameId": null,
			"roundness": null,
			"boundElements": [],
			"updated": 1711823450643,
			"link": null,
			"locked": false,
			"fontSize": 20,
			"fontFamily": 1,
			"text": "8",
			"rawText": "8",
			"textAlign": "center",
			"verticalAlign": "middle",
			"containerId": "wcmA01sqSDBKsLx3GLCXA",
			"originalText": "8",
			"lineHeight": 1.25
		},
		{
			"type": "arrow",
			"version": 476,
			"versionNonce": 1865699431,
			"isDeleted": false,
			"id": "poeBGR7nkOoXHoHTLJWXH",
			"fillStyle": "solid",
			"strokeWidth": 2,
			"strokeStyle": "solid",
			"roughness": 1,
			"opacity": 100,
			"angle": 0,
			"x": -197.66665649414062,
			"y": -389.45314025878906,
			"strokeColor": "#1e1e1e",
			"backgroundColor": "transparent",
			"width": 71.33334350585938,
			"height": 477.24095653398,
			"seed": 94077255,
			"groupIds": [],
			"frameId": null,
			"roundness": {
				"type": 2
			},
			"boundElements": [
				{
					"type": "text",
					"id": "nSBoxbeC"
				}
			],
			"updated": 1712073796484,
			"link": null,
			"locked": false,
			"startBinding": {
				"elementId": "0TH1Q8r3-1oxOPPtuFwd4",
				"gap": 11.666717529296875,
				"focus": 1.1133177333880482
			},
			"endBinding": {
				"elementId": "PS8zbXU0lQo1gIlCx1VKb",
				"gap": 10.6666259765625,
				"focus": -0.7874386316957953
			},
			"lastCommittedPoint": null,
			"startArrowhead": null,
			"endArrowhead": "arrow",
			"points": [
				[
					0,
					0
				],
				[
					-71.33334350585938,
					159.3333740234375
				],
				[
					-16.267917604856564,
					477.24095653398
				]
			]
		},
		{
			"type": "text",
			"version": 2,
			"versionNonce": 1588182985,
			"isDeleted": false,
			"id": "nSBoxbeC",
			"fillStyle": "solid",
			"strokeWidth": 2,
			"strokeStyle": "solid",
			"roughness": 1,
			"opacity": 100,
			"angle": 0,
			"x": -284.37999725341797,
			"y": 147.3802490234375,
			"strokeColor": "#1e1e1e",
			"backgroundColor": "transparent",
			"width": 10.759994506835938,
			"height": 25,
			"seed": 1324034023,
			"groupIds": [],
			"frameId": null,
			"roundness": null,
			"boundElements": [],
			"updated": 1711823448673,
			"link": null,
			"locked": false,
			"fontSize": 20,
			"fontFamily": 1,
			"text": "7",
			"rawText": "7",
			"textAlign": "center",
			"verticalAlign": "middle",
			"containerId": "poeBGR7nkOoXHoHTLJWXH",
			"originalText": "7",
			"lineHeight": 1.25
		},
		{
			"type": "rectangle",
			"version": 247,
			"versionNonce": 674690633,
			"isDeleted": false,
			"id": "vB3-QNQbCS5LsWFsH6LrE",
			"fillStyle": "solid",
			"strokeWidth": 2,
			"strokeStyle": "solid",
			"roughness": 1,
			"opacity": 100,
			"angle": 0,
			"x": -267.6667175292969,
			"y": -553.4531402587891,
			"strokeColor": "#1e1e1e",
			"backgroundColor": "transparent",
			"width": 92.66665649414062,
			"height": 60,
			"seed": 998596263,
			"groupIds": [],
			"frameId": null,
			"roundness": {
				"type": 3
			},
			"boundElements": [
				{
					"type": "text",
					"id": "82Awlkmj"
				},
				{
					"id": "uCttJyokoXdWlUvNB0RQG",
					"type": "arrow"
				},
				{
					"id": "5Zj_0U34enpYEs7bhw5o1",
					"type": "arrow"
				}
			],
			"updated": 1711823525700,
			"link": null,
			"locked": false
		},
		{
			"type": "text",
			"version": 229,
			"versionNonce": 1282622761,
			"isDeleted": false,
			"id": "82Awlkmj",
			"fillStyle": "solid",
			"strokeWidth": 2,
			"strokeStyle": "solid",
			"roughness": 1,
			"opacity": 100,
			"angle": 0,
			"x": -259.31334686279297,
			"y": -548.4531402587891,
			"strokeColor": "#1e1e1e",
			"backgroundColor": "transparent",
			"width": 75.95991516113281,
			"height": 50,
			"seed": 650604871,
			"groupIds": [],
			"frameId": null,
			"roundness": null,
			"boundElements": [],
			"updated": 1711823525700,
			"link": null,
			"locked": false,
			"fontSize": 20,
			"fontFamily": 1,
			"text": "Wash\nSolution",
			"rawText": "Wash Solution",
			"textAlign": "center",
			"verticalAlign": "middle",
			"containerId": "vB3-QNQbCS5LsWFsH6LrE",
			"originalText": "Wash Solution",
			"lineHeight": 1.25
		},
		{
			"type": "arrow",
			"version": 319,
			"versionNonce": 1473745639,
			"isDeleted": false,
			"id": "aO0yKPbcSyfrLUch1YeXE",
			"fillStyle": "solid",
			"strokeWidth": 2,
			"strokeStyle": "solid",
			"roughness": 1,
			"opacity": 100,
			"angle": 0,
			"x": -50.577121446075644,
			"y": -493.45314025878906,
			"strokeColor": "#1e1e1e",
			"backgroundColor": "transparent",
			"width": 41.93814267653189,
			"height": 83.3333740234375,
			"seed": 1356384999,
			"groupIds": [],
			"frameId": null,
			"roundness": {
				"type": 2
			},
			"boundElements": [
				{
					"type": "text",
					"id": "dt2o3Fhl"
				}
			],
			"updated": 1712073796472,
			"link": null,
			"locked": false,
			"startBinding": {
				"elementId": "ODWRP1MtLcp3Vh7PsQYtS",
				"gap": 6.3333587646484375,
				"focus": 0.6054416299564795
			},
			"endBinding": {
				"elementId": "0TH1Q8r3-1oxOPPtuFwd4",
				"gap": 10.999908447265625,
				"focus": 0.3239126285683082
			},
			"lastCommittedPoint": null,
			"startArrowhead": null,
			"endArrowhead": "arrow",
			"points": [
				[
					0,
					0
				],
				[
					-41.93814267653189,
					83.3333740234375
				]
			]
		},
		{
			"type": "text",
			"version": 2,
			"versionNonce": 770994247,
			"isDeleted": false,
			"id": "dt2o3Fhl",
			"fillStyle": "solid",
			"strokeWidth": 2,
			"strokeStyle": "solid",
			"roughness": 1,
			"opacity": 100,
			"angle": 0,
			"x": -91.47665405273438,
			"y": -55.953094482421875,
			"strokeColor": "#1e1e1e",
			"backgroundColor": "transparent",
			"width": 13.6199951171875,
			"height": 25,
			"seed": 451267337,
			"groupIds": [],
			"frameId": null,
			"roundness": null,
			"boundElements": [],
			"updated": 1711823438098,
			"link": null,
			"locked": false,
			"fontSize": 20,
			"fontFamily": 1,
			"text": "3",
			"rawText": "3",
			"textAlign": "center",
			"verticalAlign": "middle",
			"containerId": "aO0yKPbcSyfrLUch1YeXE",
			"originalText": "3",
			"lineHeight": 1.25
		},
		{
			"type": "arrow",
			"version": 335,
			"versionNonce": 1557278727,
			"isDeleted": false,
			"id": "uCttJyokoXdWlUvNB0RQG",
			"fillStyle": "solid",
			"strokeWidth": 2,
			"strokeStyle": "solid",
			"roughness": 1,
			"opacity": 100,
			"angle": 0,
			"x": -211.91273160899635,
			"y": -478.7864532470703,
			"strokeColor": "#1e1e1e",
			"backgroundColor": "transparent",
			"width": 45.33331298828122,
			"height": 66,
			"seed": 1080305577,
			"groupIds": [],
			"frameId": null,
			"roundness": {
				"type": 2
			},
			"boundElements": [
				{
					"type": "text",
					"id": "7IcscnHT"
				}
			],
			"updated": 1712073796489,
			"link": null,
			"locked": false,
			"startBinding": {
				"elementId": "vB3-QNQbCS5LsWFsH6LrE",
				"gap": 14.66668701171875,
				"focus": -0.2635543199530669
			},
			"endBinding": {
				"elementId": "0TH1Q8r3-1oxOPPtuFwd4",
				"gap": 13.666595458984375,
				"focus": 0.4107903219013989
			},
			"lastCommittedPoint": null,
			"startArrowhead": null,
			"endArrowhead": "arrow",
			"points": [
				[
					0,
					0
				],
				[
					-3.087268391003647,
					40.666687011718736
				],
				[
					42.246044597277574,
					66
				]
			]
		},
		{
			"type": "text",
			"version": 2,
			"versionNonce": 130253385,
			"isDeleted": false,
			"id": "7IcscnHT",
			"fillStyle": "solid",
			"strokeWidth": 2,
			"strokeStyle": "solid",
			"roughness": 1,
			"opacity": 100,
			"angle": 0,
			"x": -190.04334259033203,
			"y": -65.61978149414062,
			"strokeColor": "#1e1e1e",
			"backgroundColor": "transparent",
			"width": 5.4199981689453125,
			"height": 25,
			"seed": 1444601191,
			"groupIds": [],
			"frameId": null,
			"roundness": null,
			"boundElements": [],
			"updated": 1711823419985,
			"link": null,
			"locked": false,
			"fontSize": 20,
			"fontFamily": 1,
			"text": "1",
			"rawText": "1",
			"textAlign": "center",
			"verticalAlign": "middle",
			"containerId": "uCttJyokoXdWlUvNB0RQG",
			"originalText": "1",
			"lineHeight": 1.25
		},
		{
			"type": "arrow",
			"version": 350,
			"versionNonce": 792500007,
			"isDeleted": false,
			"id": "5Zj_0U34enpYEs7bhw5o1",
			"fillStyle": "solid",
			"strokeWidth": 2,
			"strokeStyle": "solid",
			"roughness": 1,
			"opacity": 100,
			"angle": 0,
			"x": -143.66668701171875,
			"y": -412.7864532470703,
			"strokeColor": "#1e1e1e",
			"backgroundColor": "transparent",
			"width": 44.936823731630795,
			"height": 70.6666259765625,
			"seed": 1046439687,
			"groupIds": [],
			"frameId": null,
			"roundness": {
				"type": 2
			},
			"boundElements": [
				{
					"type": "text",
					"id": "HzHET0HD"
				}
			],
			"updated": 1712073796490,
			"link": null,
			"locked": false,
			"startBinding": {
				"elementId": "0TH1Q8r3-1oxOPPtuFwd4",
				"gap": 13.666595458984375,
				"focus": 0.05451068533378006
			},
			"endBinding": {
				"elementId": "vB3-QNQbCS5LsWFsH6LrE",
				"gap": 10.00006103515625,
				"focus": 0.11867564667881057
			},
			"lastCommittedPoint": null,
			"startArrowhead": null,
			"endArrowhead": "arrow",
			"points": [
				[
					0,
					0
				],
				[
					-10.66668701171875,
					-38
				],
				[
					-44.936823731630795,
					-70.6666259765625
				]
			]
		},
		{
			"type": "text",
			"version": 2,
			"versionNonce": 669632103,
			"isDeleted": false,
			"id": "HzHET0HD",
			"fillStyle": "solid",
			"strokeWidth": 2,
			"strokeStyle": "solid",
			"roughness": 1,
			"opacity": 100,
			"angle": 0,
			"x": -167.45333862304688,
			"y": -67.95309448242188,
			"strokeColor": "#1e1e1e",
			"backgroundColor": "transparent",
			"width": 14.239990234375,
			"height": 25,
			"seed": 44620521,
			"groupIds": [],
			"frameId": null,
			"roundness": null,
			"boundElements": [],
			"updated": 1711823421522,
			"link": null,
			"locked": false,
			"fontSize": 20,
			"fontFamily": 1,
			"text": "2",
			"rawText": "2",
			"textAlign": "center",
			"verticalAlign": "middle",
			"containerId": "5Zj_0U34enpYEs7bhw5o1",
			"originalText": "2",
			"lineHeight": 1.25
		},
		{
			"type": "rectangle",
			"version": 377,
			"versionNonce": 1053524393,
			"isDeleted": false,
			"id": "s4hK47-l119G44Vr6KyQj",
			"fillStyle": "solid",
			"strokeWidth": 2,
			"strokeStyle": "solid",
			"roughness": 1,
			"opacity": 100,
			"angle": 0,
			"x": 216.27903122564533,
			"y": -524.8278234906686,
			"strokeColor": "#1e1e1e",
			"backgroundColor": "transparent",
			"width": 120,
			"height": 69.3333740234375,
			"seed": 1648702055,
			"groupIds": [],
			"frameId": null,
			"roundness": {
				"type": 3
			},
			"boundElements": [
				{
					"type": "text",
					"id": "VKspB7Ql"
				},
				{
					"id": "Q9TIKDFtSWsWlMSElXdRT",
					"type": "arrow"
				},
				{
					"id": "nsKn9Tmc4jUIkaFDwNtvG",
					"type": "arrow"
				},
				{
					"id": "YjDV_4WW3z9hB24ijSn9G",
					"type": "arrow"
				},
				{
					"id": "JQg1EVCmWN3IGGqnq1WWz",
					"type": "arrow"
				},
				{
					"id": "VVuTYSAhCJ6l3UXlKMnQP",
					"type": "arrow"
				},
				{
					"id": "QGuaTMSs1eI9rHBtiVNu1",
					"type": "arrow"
				}
			],
			"updated": 1711824295824,
			"link": null,
			"locked": false
		},
		{
			"type": "text",
			"version": 368,
			"versionNonce": 363131849,
			"isDeleted": false,
			"id": "VKspB7Ql",
			"fillStyle": "solid",
			"strokeWidth": 2,
			"strokeStyle": "solid",
			"roughness": 1,
			"opacity": 100,
			"angle": 0,
			"x": 237.89906448980548,
			"y": -515.1611364789499,
			"strokeColor": "#1e1e1e",
			"backgroundColor": "transparent",
			"width": 76.75993347167969,
			"height": 50,
			"seed": 1742753159,
			"groupIds": [],
			"frameId": null,
			"roundness": null,
			"boundElements": [],
			"updated": 1711823770097,
			"link": null,
			"locked": false,
			"fontSize": 20,
			"fontFamily": 1,
			"text": "Thermal\nControl",
			"rawText": "Thermal Control",
			"textAlign": "center",
			"verticalAlign": "middle",
			"containerId": "s4hK47-l119G44Vr6KyQj",
			"originalText": "Thermal Control",
			"lineHeight": 1.25
		},
		{
			"type": "arrow",
			"version": 155,
			"versionNonce": 1243625831,
			"isDeleted": false,
			"id": "Q9TIKDFtSWsWlMSElXdRT",
			"fillStyle": "solid",
			"strokeWidth": 2,
			"strokeStyle": "solid",
			"roughness": 1,
			"opacity": 100,
			"angle": 0,
			"x": 206.420655716995,
			"y": -456.8676258018321,
			"strokeColor": "#1e1e1e",
			"backgroundColor": "transparent",
			"width": 119.6032895609267,
			"height": 73.64383688159705,
			"seed": 1463578183,
			"groupIds": [],
			"frameId": null,
			"roundness": {
				"type": 2
			},
			"boundElements": [
				{
					"type": "text",
					"id": "S0jkShm5"
				}
			],
			"updated": 1712073796492,
			"link": null,
			"locked": false,
			"startBinding": {
				"elementId": "s4hK47-l119G44Vr6KyQj",
				"gap": 9.85837550865034,
				"focus": 0.13574333911949796
			},
			"endBinding": {
				"elementId": "bU9Jms2O_zU1_lSFDH0oY",
				"gap": 9.817244085755789,
				"focus": 0.13772057568558313
			},
			"lastCommittedPoint": null,
			"startArrowhead": null,
			"endArrowhead": "arrow",
			"points": [
				[
					0,
					0
				],
				[
					-119.6032895609267,
					73.64383688159705
				]
			]
		},
		{
			"type": "text",
			"version": 8,
			"versionNonce": 1724045033,
			"isDeleted": false,
			"id": "S0jkShm5",
			"fillStyle": "solid",
			"strokeWidth": 2,
			"strokeStyle": "solid",
			"roughness": 1,
			"opacity": 100,
			"angle": 0,
			"x": 133.09902192285978,
			"y": -432.5457073610336,
			"strokeColor": "#1e1e1e",
			"backgroundColor": "transparent",
			"width": 27.03997802734375,
			"height": 25,
			"seed": 911678759,
			"groupIds": [],
			"frameId": null,
			"roundness": null,
			"boundElements": [],
			"updated": 1711824525083,
			"link": null,
			"locked": false,
			"fontSize": 20,
			"fontFamily": 1,
			"text": "24",
			"rawText": "24",
			"textAlign": "center",
			"verticalAlign": "middle",
			"containerId": "Q9TIKDFtSWsWlMSElXdRT",
			"originalText": "24",
			"lineHeight": 1.25
		},
		{
			"type": "arrow",
			"version": 196,
			"versionNonce": 833637287,
			"isDeleted": false,
			"id": "nsKn9Tmc4jUIkaFDwNtvG",
			"fillStyle": "solid",
			"strokeWidth": 2,
			"strokeStyle": "solid",
			"roughness": 1,
			"opacity": 100,
			"angle": 0,
			"x": 204.4802045058778,
			"y": -507.9168020182621,
			"strokeColor": "#1e1e1e",
			"backgroundColor": "transparent",
			"width": 77.62047645151236,
			"height": 23.495233415603764,
			"seed": 1147261289,
			"groupIds": [],
			"frameId": null,
			"roundness": {
				"type": 2
			},
			"boundElements": [
				{
					"type": "text",
					"id": "kDEbEBqd"
				}
			],
			"updated": 1712073796494,
			"link": null,
			"locked": false,
			"startBinding": {
				"elementId": "s4hK47-l119G44Vr6KyQj",
				"gap": 11.798826719767533,
				"focus": -0.07528900117174889
			},
			"endBinding": {
				"elementId": "ODWRP1MtLcp3Vh7PsQYtS",
				"gap": 15.526476101240462,
				"focus": -0.4222636745200769
			},
			"lastCommittedPoint": null,
			"startArrowhead": null,
			"endArrowhead": "arrow",
			"points": [
				[
					0,
					0
				],
				[
					-77.62047645151236,
					-23.495233415603764
				]
			]
		},
		{
			"type": "text",
			"version": 5,
			"versionNonce": 120743241,
			"isDeleted": false,
			"id": "kDEbEBqd",
			"fillStyle": "solid",
			"strokeWidth": 2,
			"strokeStyle": "solid",
			"roughness": 1,
			"opacity": 100,
			"angle": 0,
			"x": 152.36997848715288,
			"y": -532.164418726064,
			"strokeColor": "#1e1e1e",
			"backgroundColor": "transparent",
			"width": 26.5999755859375,
			"height": 25,
			"seed": 191234569,
			"groupIds": [],
			"frameId": null,
			"roundness": null,
			"boundElements": [],
			"updated": 1711824527875,
			"link": null,
			"locked": false,
			"fontSize": 20,
			"fontFamily": 1,
			"text": "25",
			"rawText": "25",
			"textAlign": "center",
			"verticalAlign": "middle",
			"containerId": "nsKn9Tmc4jUIkaFDwNtvG",
			"originalText": "25",
			"lineHeight": 1.25
		},
		{
			"type": "arrow",
			"version": 295,
			"versionNonce": 1695956679,
			"isDeleted": false,
			"id": "YjDV_4WW3z9hB24ijSn9G",
			"fillStyle": "solid",
			"strokeWidth": 2,
			"strokeStyle": "solid",
			"roughness": 1,
			"opacity": 100,
			"angle": 0,
			"x": 224.91063013325618,
			"y": -539.9675511294836,
			"strokeColor": "#1e1e1e",
			"backgroundColor": "transparent",
			"width": 342.55521635916705,
			"height": 249.67900382742528,
			"seed": 1775898727,
			"groupIds": [],
			"frameId": null,
			"roundness": {
				"type": 2
			},
			"boundElements": [
				{
					"type": "text",
					"id": "sT7MlVia"
				}
			],
			"updated": 1712073796495,
			"link": null,
			"locked": false,
			"startBinding": {
				"elementId": "s4hK47-l119G44Vr6KyQj",
				"gap": 15.139727638814975,
				"focus": 0.38736437990844497
			},
			"endBinding": {
				"elementId": "0TH1Q8r3-1oxOPPtuFwd4",
				"gap": 12.774034518711346,
				"focus": 0.017031367753577803
			},
			"lastCommittedPoint": null,
			"startArrowhead": null,
			"endArrowhead": "arrow",
			"points": [
				[
					0,
					0
				],
				[
					-249.41071568096652,
					-121.60534500473898
				],
				[
					-342.55521635916705,
					128.0736588226863
				]
			]
		},
		{
			"type": "text",
			"version": 3,
			"versionNonce": 1423527047,
			"isDeleted": false,
			"id": "sT7MlVia",
			"fillStyle": "solid",
			"strokeWidth": 2,
			"strokeStyle": "solid",
			"roughness": 1,
			"opacity": 100,
			"angle": 0,
			"x": -33.30008097007362,
			"y": -674.0728961342226,
			"strokeColor": "#1e1e1e",
			"backgroundColor": "transparent",
			"width": 17.599990844726562,
			"height": 25,
			"seed": 1688510441,
			"groupIds": [],
			"frameId": null,
			"roundness": null,
			"boundElements": [],
			"updated": 1711823842994,
			"link": null,
			"locked": false,
			"fontSize": 20,
			"fontFamily": 1,
			"text": "19",
			"rawText": "19",
			"textAlign": "center",
			"verticalAlign": "middle",
			"containerId": "YjDV_4WW3z9hB24ijSn9G",
			"originalText": "19",
			"lineHeight": 1.25
		},
		{
			"type": "arrow",
			"version": 465,
			"versionNonce": 428920295,
			"isDeleted": false,
			"id": "JQg1EVCmWN3IGGqnq1WWz",
			"fillStyle": "solid",
			"strokeWidth": 2,
			"strokeStyle": "solid",
			"roughness": 1,
			"opacity": 100,
			"angle": 0,
			"x": -79.13976209648283,
			"y": 163.32659955626656,
			"strokeColor": "#1e1e1e",
			"backgroundColor": "transparent",
			"width": 372.88344641896924,
			"height": 608.2092580161112,
			"seed": 1239190823,
			"groupIds": [],
			"frameId": null,
			"roundness": {
				"type": 2
			},
			"boundElements": [
				{
					"type": "text",
					"id": "eN7tv0N0"
				}
			],
			"updated": 1712073796496,
			"link": null,
			"locked": false,
			"startBinding": {
				"elementId": "PS8zbXU0lQo1gIlCx1VKb",
				"gap": 14.967894365454839,
				"focus": 1.0516482295253329
			},
			"endBinding": {
				"elementId": "s4hK47-l119G44Vr6KyQj",
				"gap": 10.611791007386444,
				"focus": -0.37421179393926496
			},
			"lastCommittedPoint": null,
			"startArrowhead": null,
			"endArrowhead": "arrow",
			"points": [
				[
					0,
					0
				],
				[
					303.6718682407985,
					-159.9513188924322
				],
				[
					372.88344641896924,
					-608.2092580161112
				]
			]
		},
		{
			"type": "text",
			"version": 3,
			"versionNonce": 1901755335,
			"isDeleted": false,
			"id": "eN7tv0N0",
			"fillStyle": "solid",
			"strokeWidth": 2,
			"strokeStyle": "solid",
			"roughness": 1,
			"opacity": 100,
			"angle": 0,
			"x": 201.8385401477878,
			"y": -76.39566864418327,
			"strokeColor": "#1e1e1e",
			"backgroundColor": "transparent",
			"width": 18.219985961914062,
			"height": 25,
			"seed": 996762793,
			"groupIds": [],
			"frameId": null,
			"roundness": null,
			"boundElements": [],
			"updated": 1711823835698,
			"link": null,
			"locked": false,
			"fontSize": 20,
			"fontFamily": 1,
			"text": "16",
			"rawText": "16",
			"textAlign": "center",
			"verticalAlign": "middle",
			"containerId": "JQg1EVCmWN3IGGqnq1WWz",
			"originalText": "16",
			"lineHeight": 1.25
		},
		{
			"type": "arrow",
			"version": 263,
			"versionNonce": 2049734919,
			"isDeleted": false,
			"id": "VVuTYSAhCJ6l3UXlKMnQP",
			"fillStyle": "solid",
			"strokeWidth": 2,
			"strokeStyle": "solid",
			"roughness": 1,
			"opacity": 100,
			"angle": 0,
			"x": 267.22327640214576,
			"y": -441.6484349287325,
			"strokeColor": "#1e1e1e",
			"backgroundColor": "transparent",
			"width": 346.70451056229774,
			"height": 581.1190626382784,
			"seed": 1303465223,
			"groupIds": [],
			"frameId": null,
			"roundness": {
				"type": 2
			},
			"boundElements": [
				{
					"type": "text",
					"id": "4mHRUdfI"
				}
			],
			"updated": 1712073796497,
			"link": null,
			"locked": false,
			"startBinding": {
				"elementId": "s4hK47-l119G44Vr6KyQj",
				"gap": 13.846014538498594,
				"focus": -0.007144023785452908
			},
			"endBinding": {
				"elementId": "PS8zbXU0lQo1gIlCx1VKb",
				"gap": 14.626422301785652,
				"focus": 0.6891849947825033
			},
			"lastCommittedPoint": null,
			"startArrowhead": null,
			"endArrowhead": "arrow",
			"points": [
				[
					0,
					0
				],
				[
					-87.32296938581294,
					444.3769182620872
				],
				[
					-346.70451056229774,
					581.1190626382784
				]
			]
		},
		{
			"type": "text",
			"version": 3,
			"versionNonce": 1793137383,
			"isDeleted": false,
			"id": "4mHRUdfI",
			"fillStyle": "solid",
			"strokeWidth": 2,
			"strokeStyle": "solid",
			"roughness": 1,
			"opacity": 100,
			"angle": 0,
			"x": 189.27490455560485,
			"y": -44.700704420970396,
			"strokeColor": "#1e1e1e",
			"backgroundColor": "transparent",
			"width": 16.17999267578125,
			"height": 25,
			"seed": 543700873,
			"groupIds": [],
			"frameId": null,
			"roundness": null,
			"boundElements": [],
			"updated": 1711823942738,
			"link": null,
			"locked": false,
			"fontSize": 20,
			"fontFamily": 1,
			"text": "17",
			"rawText": "17",
			"textAlign": "center",
			"verticalAlign": "middle",
			"containerId": "VVuTYSAhCJ6l3UXlKMnQP",
			"originalText": "17",
			"lineHeight": 1.25
		},
		{
			"type": "rectangle",
			"version": 751,
			"versionNonce": 1166518249,
			"isDeleted": false,
			"id": "aoeJN_47iDl4VfhN65hFS",
			"fillStyle": "solid",
			"strokeWidth": 2,
			"strokeStyle": "solid",
			"roughness": 1,
			"opacity": 100,
			"angle": 0,
			"x": -172.21212274530404,
			"y": -106.83250354895324,
			"strokeColor": "#1e1e1e",
			"backgroundColor": "transparent",
			"width": 102.6666259765625,
			"height": 60,
			"seed": 632852713,
			"groupIds": [],
			"frameId": null,
			"roundness": {
				"type": 3
			},
			"boundElements": [
				{
					"type": "text",
					"id": "oH1eUweU"
				},
				{
					"id": "qAOtm6owThPo9_yYwTpe4",
					"type": "arrow"
				},
				{
					"id": "RTg3Z9sVvfRC_algMN-aO",
					"type": "arrow"
				},
				{
					"id": "GrVChs8RONhCqfv4I8e7B",
					"type": "arrow"
				},
				{
					"id": "TLeKdNhl8hJ3KNtLr0rVx",
					"type": "arrow"
				},
				{
					"id": "cscG2V1hwLWiyM6O2XQi9",
					"type": "arrow"
				},
				{
					"id": "QGuaTMSs1eI9rHBtiVNu1",
					"type": "arrow"
				}
			],
			"updated": 1711824295824,
			"link": null,
			"locked": false
		},
		{
			"type": "text",
			"version": 782,
			"versionNonce": 937863431,
			"isDeleted": false,
			"id": "oH1eUweU",
			"fillStyle": "solid",
			"strokeWidth": 2,
			"strokeStyle": "solid",
			"roughness": 1,
			"opacity": 100,
			"angle": 0,
			"x": -148.88878137567514,
			"y": -101.83250354895324,
			"strokeColor": "#1e1e1e",
			"backgroundColor": "transparent",
			"width": 56.01994323730469,
			"height": 50,
			"seed": 1747487689,
			"groupIds": [],
			"frameId": null,
			"roundness": null,
			"boundElements": [],
			"updated": 1711824257682,
			"link": null,
			"locked": false,
			"fontSize": 20,
			"fontFamily": 1,
			"text": "Mains\nPower",
			"rawText": "Mains Power",
			"textAlign": "center",
			"verticalAlign": "middle",
			"containerId": "aoeJN_47iDl4VfhN65hFS",
			"originalText": "Mains Power",
			"lineHeight": 1.25
		},
		{
			"type": "arrow",
			"version": 64,
			"versionNonce": 841556807,
			"isDeleted": false,
			"id": "qAOtm6owThPo9_yYwTpe4",
			"fillStyle": "solid",
			"strokeWidth": 2,
			"strokeStyle": "solid",
			"roughness": 1,
			"opacity": 100,
			"angle": 0,
			"x": -150.6332635494399,
			"y": -38.02223571335787,
			"strokeColor": "#1e1e1e",
			"backgroundColor": "transparent",
			"width": 12.93677568509139,
			"height": 128.0736884325256,
			"seed": 186078023,
			"groupIds": [],
			"frameId": null,
			"roundness": {
				"type": 2
			},
			"boundElements": [
				{
					"type": "text",
					"id": "8Dt4diBY"
				}
			],
			"updated": 1712073796500,
			"link": null,
			"locked": false,
			"startBinding": {
				"elementId": "aoeJN_47iDl4VfhN65hFS",
				"gap": 8.810267835595369,
				"focus": 0.37245827823610217
			},
			"endBinding": {
				"elementId": "PS8zbXU0lQo1gIlCx1VKb",
				"gap": 8.402989532585707,
				"focus": -0.13924940727255816
			},
			"lastCommittedPoint": null,
			"startArrowhead": null,
			"endArrowhead": "arrow",
			"points": [
				[
					0,
					0
				],
				[
					-12.93677568509139,
					60.8026206851506
				],
				[
					-12.2899191349332,
					128.0736884325256
				]
			]
		},
		{
			"type": "text",
			"version": 3,
			"versionNonce": 1123534151,
			"isDeleted": false,
			"id": "8Dt4diBY",
			"fillStyle": "solid",
			"strokeWidth": 2,
			"strokeStyle": "solid",
			"roughness": 1,
			"opacity": 100,
			"angle": 0,
			"x": -170.70821579268778,
			"y": 13.514608502904935,
			"strokeColor": "#1e1e1e",
			"backgroundColor": "transparent",
			"width": 27.8599853515625,
			"height": 25,
			"seed": 2090513193,
			"groupIds": [],
			"frameId": null,
			"roundness": null,
			"boundElements": [],
			"updated": 1711824369187,
			"link": null,
			"locked": false,
			"fontSize": 20,
			"fontFamily": 1,
			"text": "23",
			"rawText": "23",
			"textAlign": "center",
			"verticalAlign": "middle",
			"containerId": "qAOtm6owThPo9_yYwTpe4",
			"originalText": "23",
			"lineHeight": 1.25
		},
		{
			"type": "arrow",
			"version": 47,
			"versionNonce": 2077434471,
			"isDeleted": false,
			"id": "RTg3Z9sVvfRC_algMN-aO",
			"fillStyle": "solid",
			"strokeWidth": 2,
			"strokeStyle": "solid",
			"roughness": 1,
			"opacity": 100,
			"angle": 0,
			"x": -136.40283398371082,
			"y": 89.40459616900955,
			"strokeColor": "#1e1e1e",
			"backgroundColor": "transparent",
			"width": 22.63926861939194,
			"height": 124.83952412109215,
			"seed": 619852745,
			"groupIds": [],
			"frameId": null,
			"roundness": {
				"type": 2
			},
			"boundElements": [
				{
					"type": "text",
					"id": "zDNTCGsT"
				}
			],
			"updated": 1712073796501,
			"link": null,
			"locked": false,
			"startBinding": {
				"elementId": "PS8zbXU0lQo1gIlCx1VKb",
				"gap": 9.049846082743898,
				"focus": 0.041756318981756024
			},
			"endBinding": {
				"elementId": "aoeJN_47iDl4VfhN65hFS",
				"gap": 11.397575596870638,
				"focus": 0.012452939195899787
			},
			"lastCommittedPoint": null,
			"startArrowhead": null,
			"endArrowhead": "arrow",
			"points": [
				[
					0,
					0
				],
				[
					22.63926861939194,
					-67.27100852769627
				],
				[
					18.111391207642043,
					-124.83952412109215
				]
			]
		},
		{
			"type": "text",
			"version": 3,
			"versionNonce": 1647933735,
			"isDeleted": false,
			"id": "zDNTCGsT",
			"fillStyle": "solid",
			"strokeWidth": 2,
			"strokeStyle": "solid",
			"roughness": 1,
			"opacity": 100,
			"angle": 0,
			"x": -142.23398516442296,
			"y": 15.131690658621665,
			"strokeColor": "#1e1e1e",
			"backgroundColor": "transparent",
			"width": 28.47998046875,
			"height": 25,
			"seed": 374127945,
			"groupIds": [],
			"frameId": null,
			"roundness": null,
			"boundElements": [],
			"updated": 1711824366371,
			"link": null,
			"locked": false,
			"fontSize": 20,
			"fontFamily": 1,
			"text": "22",
			"rawText": "22",
			"textAlign": "center",
			"verticalAlign": "middle",
			"containerId": "RTg3Z9sVvfRC_algMN-aO",
			"originalText": "22",
			"lineHeight": 1.25
		},
		{
			"type": "arrow",
			"version": 61,
			"versionNonce": 2049981831,
			"isDeleted": false,
			"id": "GrVChs8RONhCqfv4I8e7B",
			"fillStyle": "solid",
			"strokeWidth": 2,
			"strokeStyle": "solid",
			"roughness": 1,
			"opacity": 100,
			"angle": 0,
			"x": -72.36604898712667,
			"y": -114.34899906455394,
			"strokeColor": "#1e1e1e",
			"backgroundColor": "transparent",
			"width": 33.63553387368748,
			"height": 216.0435143684967,
			"seed": 1847164551,
			"groupIds": [],
			"frameId": null,
			"roundness": {
				"type": 2
			},
			"boundElements": [
				{
					"type": "text",
					"id": "o0szQ5ke"
				}
			],
			"updated": 1712073796502,
			"link": null,
			"locked": false,
			"startBinding": {
				"elementId": "aoeJN_47iDl4VfhN65hFS",
				"gap": 7.516495515600695,
				"focus": 0.7889683043336604
			},
			"endBinding": {
				"elementId": "0TH1Q8r3-1oxOPPtuFwd4",
				"gap": 8.727344355035314,
				"focus": -0.5065626708766212
			},
			"lastCommittedPoint": null,
			"startArrowhead": null,
			"endArrowhead": "arrow",
			"points": [
				[
					0,
					0
				],
				[
					14.230429565729054,
					-108.66858412456713
				],
				[
					-19.405104307958425,
					-216.0435143684967
				]
			]
		},
		{
			"type": "text",
			"version": 3,
			"versionNonce": 784484521,
			"isDeleted": false,
			"id": "o0szQ5ke",
			"fillStyle": "solid",
			"strokeWidth": 2,
			"strokeStyle": "solid",
			"roughness": 1,
			"opacity": 100,
			"angle": 0,
			"x": -67.96561362305778,
			"y": -235.51758318912107,
			"strokeColor": "#1e1e1e",
			"backgroundColor": "transparent",
			"width": 19.659988403320312,
			"height": 25,
			"seed": 1508400615,
			"groupIds": [],
			"frameId": null,
			"roundness": null,
			"boundElements": [],
			"updated": 1711824362243,
			"link": null,
			"locked": false,
			"fontSize": 20,
			"fontFamily": 1,
			"text": "21",
			"rawText": "21",
			"textAlign": "center",
			"verticalAlign": "middle",
			"containerId": "GrVChs8RONhCqfv4I8e7B",
			"originalText": "21",
			"lineHeight": 1.25
		},
		{
			"type": "arrow",
			"version": 80,
			"versionNonce": 1618801831,
			"isDeleted": false,
			"id": "TLeKdNhl8hJ3KNtLr0rVx",
			"fillStyle": "solid",
			"strokeWidth": 2,
			"strokeStyle": "solid",
			"roughness": 1,
			"opacity": 100,
			"angle": 0,
			"x": -54.901455109964104,
			"y": -80.71352441054499,
			"strokeColor": "#1e1e1e",
			"backgroundColor": "transparent",
			"width": 64.683700766421,
			"height": 29.754453792417294,
			"seed": 1768022631,
			"groupIds": [],
			"frameId": null,
			"roundness": {
				"type": 2
			},
			"boundElements": [
				{
					"type": "text",
					"id": "9JnUwH7v"
				}
			],
			"updated": 1712073796504,
			"link": null,
			"locked": false,
			"startBinding": {
				"elementId": "aoeJN_47iDl4VfhN65hFS",
				"gap": 14.64404165877744,
				"focus": 0.6197875922449986
			},
			"endBinding": {
				"elementId": "3vFeRiSeK2OI2f1WuSYI6",
				"gap": 9.217815378699356,
				"focus": 0.7337016299857904
			},
			"lastCommittedPoint": null,
			"startArrowhead": null,
			"endArrowhead": "arrow",
			"points": [
				[
					0,
					0
				],
				[
					24.579838269866457,
					-16.17088077684629
				],
				[
					64.683700766421,
					-29.754453792417294
				]
			]
		},
		{
			"type": "text",
			"version": 3,
			"versionNonce": 1408902503,
			"isDeleted": false,
			"id": "9JnUwH7v",
			"fillStyle": "solid",
			"strokeWidth": 2,
			"strokeStyle": "solid",
			"roughness": 1,
			"opacity": 100,
			"angle": 0,
			"x": -31.359600149116886,
			"y": -108.09075130675365,
			"strokeColor": "#1e1e1e",
			"backgroundColor": "transparent",
			"width": 17.599990844726562,
			"height": 25,
			"seed": 1033229577,
			"groupIds": [],
			"frameId": null,
			"roundness": null,
			"boundElements": [],
			"updated": 1711824349586,
			"link": null,
			"locked": false,
			"fontSize": 20,
			"fontFamily": 1,
			"text": "19",
			"rawText": "19",
			"textAlign": "center",
			"verticalAlign": "middle",
			"containerId": "TLeKdNhl8hJ3KNtLr0rVx",
			"originalText": "19",
			"lineHeight": 1.25
		},
		{
			"type": "arrow",
			"version": 44,
			"versionNonce": 436680423,
			"isDeleted": false,
			"id": "cscG2V1hwLWiyM6O2XQi9",
			"fillStyle": "solid",
			"strokeWidth": 2,
			"strokeStyle": "solid",
			"roughness": 1,
			"opacity": 100,
			"angle": 0,
			"x": -58.13561942139762,
			"y": -102.70593647977888,
			"strokeColor": "#1e1e1e",
			"backgroundColor": "transparent",
			"width": 67.91786507785451,
			"height": 98.96603197058799,
			"seed": 1850253095,
			"groupIds": [],
			"frameId": null,
			"roundness": {
				"type": 2
			},
			"boundElements": [
				{
					"type": "text",
					"id": "PlxXwrGl"
				}
			],
			"updated": 1712073796504,
			"link": null,
			"locked": false,
			"startBinding": {
				"elementId": "aoeJN_47iDl4VfhN65hFS",
				"gap": 11.409877347343922,
				"focus": 0.6254997828667109
			},
			"endBinding": {
				"elementId": "dKkvgd4W00acrC5qZFvRn",
				"gap": 7.551097849402481,
				"focus": 0.6454149186626743
			},
			"lastCommittedPoint": null,
			"startArrowhead": null,
			"endArrowhead": "arrow",
			"points": [
				[
					0,
					0
				],
				[
					67.91786507785451,
					-98.96603197058799
				]
			]
		},
		{
			"type": "text",
			"version": 5,
			"versionNonce": 1190134919,
			"isDeleted": false,
			"id": "PlxXwrGl",
			"fillStyle": "solid",
			"strokeWidth": 2,
			"strokeStyle": "solid",
			"roughness": 1,
			"opacity": 100,
			"angle": 0,
			"x": -38.17667925307583,
			"y": -164.68895246507287,
			"strokeColor": "#1e1e1e",
			"backgroundColor": "transparent",
			"width": 27.999984741210938,
			"height": 25,
			"seed": 818814505,
			"groupIds": [],
			"frameId": null,
			"roundness": null,
			"boundElements": [],
			"updated": 1711824359538,
			"link": null,
			"locked": false,
			"fontSize": 20,
			"fontFamily": 1,
			"text": "20",
			"rawText": "20",
			"textAlign": "center",
			"verticalAlign": "middle",
			"containerId": "cscG2V1hwLWiyM6O2XQi9",
			"originalText": "20",
			"lineHeight": 1.25
		},
		{
			"type": "arrow",
			"version": 346,
			"versionNonce": 1374536199,
			"isDeleted": false,
			"id": "QGuaTMSs1eI9rHBtiVNu1",
			"fillStyle": "solid",
			"strokeWidth": 2,
			"strokeStyle": "solid",
			"roughness": 1,
			"opacity": 100,
			"angle": 0,
			"x": -67.28313294905774,
			"y": -36.32246343102338,
			"strokeColor": "#1e1e1e",
			"backgroundColor": "transparent",
			"width": 383.6660266712578,
			"height": 426.9123836046035,
			"seed": 2073497831,
			"groupIds": [],
			"frameId": null,
			"roundness": {
				"type": 2
			},
			"boundElements": [
				{
					"type": "text",
					"id": "sdlnf21B"
				}
			],
			"updated": 1712073796505,
			"link": null,
			"locked": false,
			"startBinding": {
				"elementId": "aoeJN_47iDl4VfhN65hFS",
				"gap": 10.750778266391194,
				"focus": 1.0864635705571737
			},
			"endBinding": {
				"elementId": "s4hK47-l119G44Vr6KyQj",
				"gap": 17.080178849932054,
				"focus": -0.7114828769400829
			},
			"lastCommittedPoint": null,
			"startArrowhead": null,
			"endArrowhead": "arrow",
			"points": [
				[
					0,
					0
				],
				[
					342.915307624545,
					24.820576418327846
				],
				[
					383.6660266712578,
					-402.0918071862757
				]
			]
		},
		{
			"type": "text",
			"version": 3,
			"versionNonce": 354686855,
			"isDeleted": false,
			"id": "sdlnf21B",
			"fillStyle": "solid",
			"strokeWidth": 2,
			"strokeStyle": "solid",
			"roughness": 1,
			"opacity": 100,
			"angle": 0,
			"x": 265.2721816945302,
			"y": -24.001887012695533,
			"strokeColor": "#1e1e1e",
			"backgroundColor": "transparent",
			"width": 20.719985961914062,
			"height": 25,
			"seed": 874153193,
			"groupIds": [],
			"frameId": null,
			"roundness": null,
			"boundElements": [],
			"updated": 1711824345894,
			"link": null,
			"locked": false,
			"fontSize": 20,
			"fontFamily": 1,
			"text": "18",
			"rawText": "18",
			"textAlign": "center",
			"verticalAlign": "middle",
			"containerId": "QGuaTMSs1eI9rHBtiVNu1",
			"originalText": "18",
			"lineHeight": 1.25
		}
	],
	"appState": {
		"theme": "light",
		"viewBackgroundColor": "#ffffff",
		"currentItemStrokeColor": "#1e1e1e",
		"currentItemBackgroundColor": "transparent",
		"currentItemFillStyle": "solid",
		"currentItemStrokeWidth": 2,
		"currentItemStrokeStyle": "solid",
		"currentItemRoughness": 1,
		"currentItemOpacity": 100,
		"currentItemFontFamily": 1,
		"currentItemFontSize": 20,
		"currentItemTextAlign": "left",
		"currentItemStartArrowhead": null,
		"currentItemEndArrowhead": "arrow",
		"scrollX": 431.0504830138863,
		"scrollY": 711.8092065961825,
		"zoom": {
			"value": 0.75
		},
		"currentItemRoundness": "round",
		"gridSize": null,
		"gridColor": {
			"Bold": "#C9C9C9FF",
			"Regular": "#EDEDEDFF"
		},
		"currentStrokeOptions": null,
		"previousGridSize": null,
		"frameRendering": {
			"enabled": true,
			"clip": true,
			"name": true,
			"outline": true
		}
	},
	"files": {}
}
```
%%

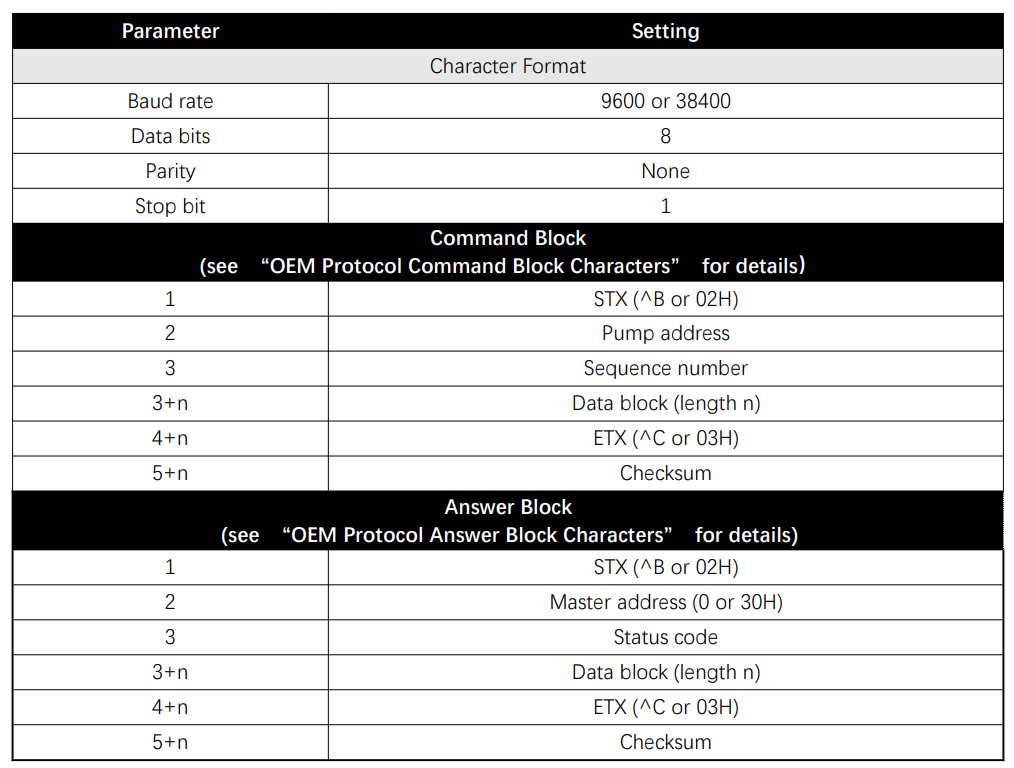
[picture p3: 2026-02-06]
AutoEC Notes/Pasted image 20240330161352.png

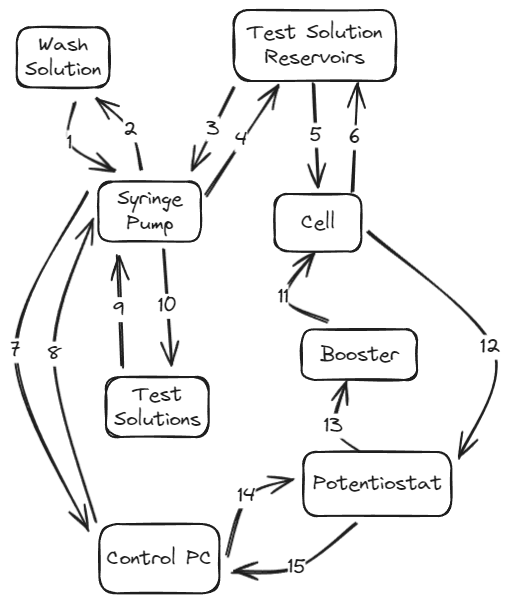
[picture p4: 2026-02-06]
AutoEC Notes/Pasted image 20240330183435.png

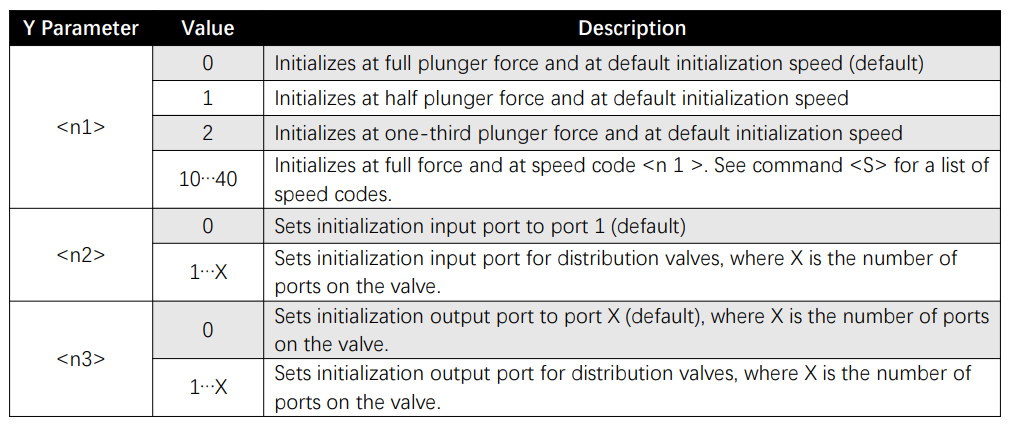
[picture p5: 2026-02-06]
AutoEC Notes/Pasted image 20240330175514.png

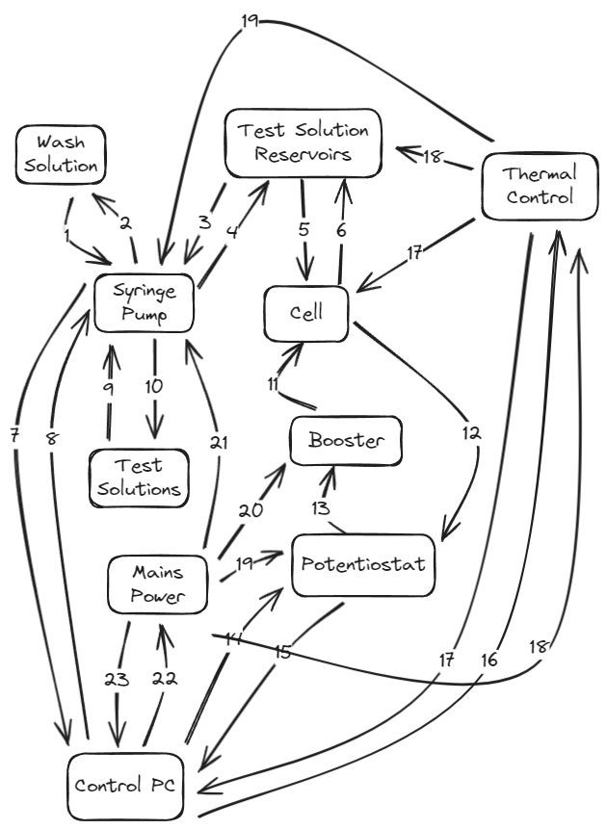
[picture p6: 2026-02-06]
AutoEC Notes/Pasted image 20240330184759.png

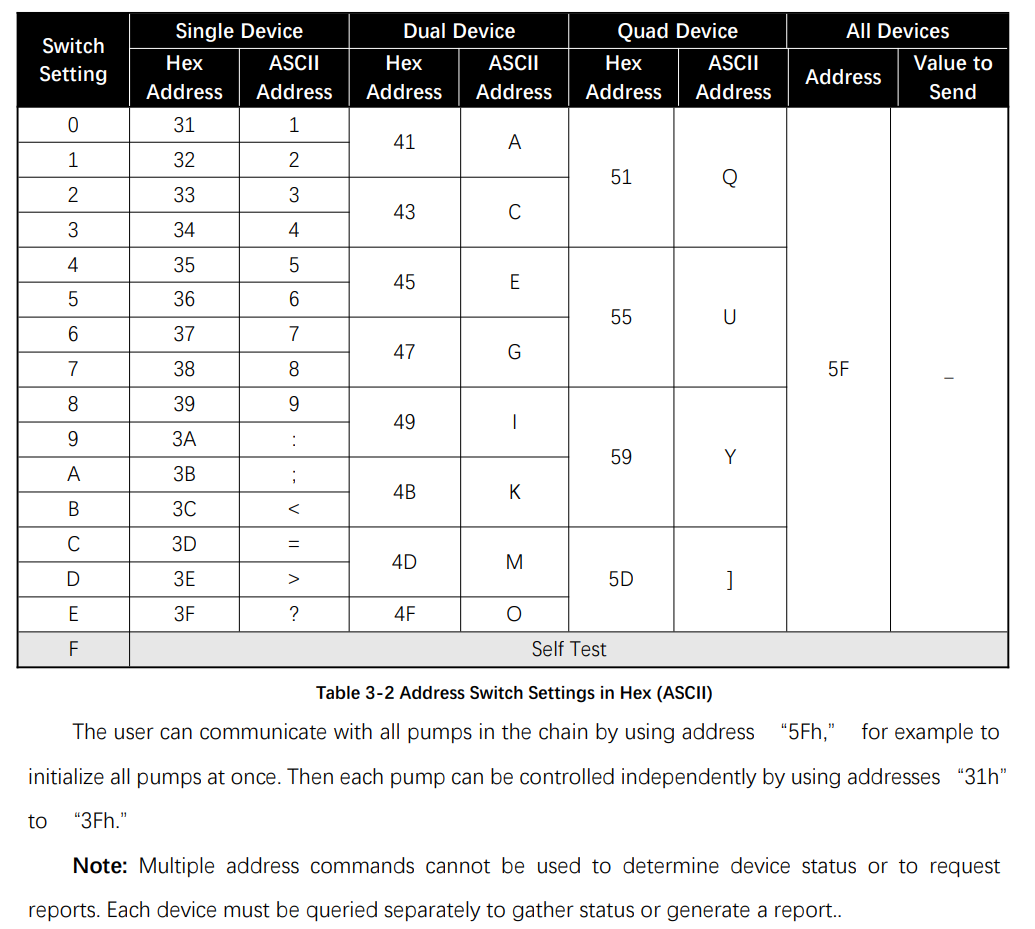
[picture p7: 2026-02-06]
AutoEC Notes/Pasted image 20240330162039.png

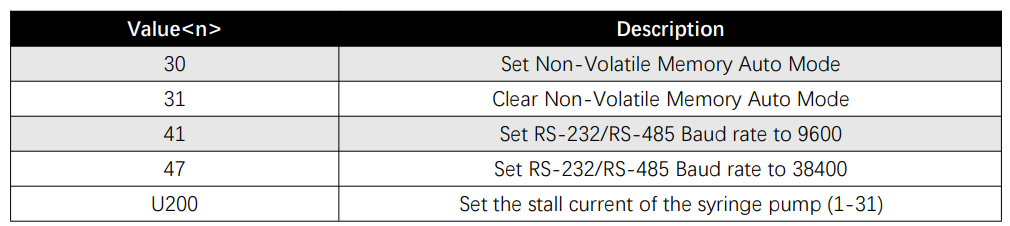
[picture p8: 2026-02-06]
AutoEC Notes/Pasted image 20240330174535.png

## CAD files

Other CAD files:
Chamber Holder.ipt
Chamber Holder_MIR.ipt
OldVersions/Side Frame.0001.ipt
OldVersions/Syringe Pump Holder.0003.ipt
OldVersions/Syringe Pump.0002.ipt
OldVersions/Top Frame.0002.ipt
OldVersions/Z bars.0001.ipt
Side Frame.ipt
Syring Pump Holder.ipt
Syringe Pump Holder.ipt
Syringe Pump.ipt
Top Frame.ipt
Z bars.ipt

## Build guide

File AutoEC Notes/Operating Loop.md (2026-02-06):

1. Intialise [[Syringe Pump]] with [[Wash Solution]]
2. Prime the pump lines
3. Flush [[Cell]] with wash
4. Dump wash
5. Fill [[Catholyte]] and [[Anolyte]] [[Reservoirs]]
6. Flush cell with test solutions
7. Initialise cell (set [[Potentiostat]] and [[Temp Controller]])
8. Take [[Measurements]]
9. Drain reservoirs
10. If not finished, go back to 2, else go to 11
11. Pause system until all samples replaced with wash solution, then flush all lines into reservoirs and dump wash periodically
12. De-initialise system and switch of

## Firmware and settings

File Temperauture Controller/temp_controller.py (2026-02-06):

from pymodbus.client import ModbusSerialClient
from pymodbus.server import ModbusSerialServer # add a simulator server for debug

def send_modbus_frame(message, port='COM3', baudrate=9600):
    # Initialize the Modbus RTU client over RS485
    client = ModbusSerialClient(
        port=port,
        baudrate=baudrate,
        timeout=1,
        stopbits=1,
        bytesize=8,
        parity='N'
    )
    
    client.connect()

    if client.connected:
    	print("connected")
    else:
    	print("not connected")

    # Calculate CRC
    highbyte, lowbyte = calculate_crc(message)
    
    # Append the CRC to the message
    message.append(lowbyte)
    message.append(highbyte)

    # Prepare the frame to be sent, adding the address at the beginning
    print("Frame to be sent:", bytes(message))

    # Send the frame to the slave device
    client.socket.write(bytes(message))

    # Optionally, read the response
    response = client.socket.read(100)  # Adjust size as necessary
    client.close()
    
    return response

def calculate_crc(message):
    crc = 0xFFFF
    
    for byte in message:
        crc ^= byte
        for _ in range(8):
            lastbit = crc & 1
            crc >>= 1
            if lastbit:
                crc ^= 0xA001
    
    highbyte = (crc >> 8) & 0xFF
    lowbyte = crc & 0xFF
    
    return highbyte, lowbyte

if __name__ == '__main__':
	message = [0x02, 0x03, 0x00, 0x7F, 0x00, 0x01]
	print(send_modbus_frame(message))

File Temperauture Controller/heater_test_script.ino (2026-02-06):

/*    Max6675 Module  ==>   Arduino
 *    CS              ==>     D10
 *    SO              ==>     D12
 *    SCK             ==>     D13
 *    Vcc             ==>     Vcc (5v)
 *    Gnd             ==>     Gnd      */

/////////////////////////////////////////////////////////////////////////////////
//imports and variables
////////////////////////////////////////////////////////////////////////////////

//user defined variables
float set_temperature = 40.0; //temp range 0-60
float set_rpm = 100.0;

//libs
#include <Wire.h> 
#include <SPI.h>
#include "DHT.h"

//define system pins
#define MAX6675_1_CS   10
#define MAX6675_1_SO   12
#define MAX6675_1_SCK  13
#define heater_1 11
#define motor_1 9
#define motor_sense_1 8
#define DHTPIN 7
#define DHTTYPE DHT11

//create humidity sensor object
DHT dht(DHTPIN, DHTTYPE);

//script variables
float temperature_read = 0.0;
float PID_error = 0;
float previous_error = 0;
float elapsedTime, Time, timePrev;
float PID_value = 0;
int PID_p = 0;   
int PID_i = 0;    
int PID_d = 0;
int counter = 1;
float hum = 0.0;
float amb_temp = 0.0;
int revs = 0;
int prev_reading = 0;
float rpm = 0.0;
int motor_val = 125;

//pid constants
int kp = 90;
int ki = 33;
int kd = 80;

/////////////////////////////////////////////////////////////////////////////////
//main script
/////////////////////////////////////////////////////////////////////////////////

void setup() {
  Time = millis();
  Serial.begin(9600);
  pinMode(heater_1,OUTPUT);
  pinMode(motor_1,OUTPUT);
  pinMode(motor_sense_1, INPUT);
  dht.begin(); //initialise the humidity sensor
  delay(100); //delay for stability
}

void loop() {
  //set temp with value
  temperature_read = readThermocouple(MAX6675_1_CS, MAX6675_1_SO, MAX6675_1_SCK);
  
  //calculate raw error and PI error terms
  PID_error = set_temperature - temperature_read + 3;
  PID_p = 0.01*kp * PID_error;
  PID_i = 0.01*PID_i + (ki * PID_error);

  //calculate PD error term
  timePrev = Time;
  Time = millis();
  elapsedTime = (Time - timePrev) / 1000; 
  PID_d = 0.01*kd*((PID_error - previous_error)/elapsedTime);
  previous_error = PID_error; //store for next loop

  //calculate full pid term and translate to pwm
  PID_value = PID_p + PID_i + PID_d;
  if(PID_value < 0)
  {    PID_value = 0;    }
  if(PID_value > 255)  
  {    PID_value = 255;  }
  analogWrite(heater_1,PID_value);

  counter = counter + 1;
  //read the humidity sensor and revs every 10s
  if (counter == 20){
    counter = 1;
    hum = dht.readHumidity();
    amb_temp = dht.readTemperature();
  }
  
  //print variables to serial
  Serial.print(temperature_read,1);
  Serial.print("\t");
  Serial.print(set_temperature);
  Serial.print("\t");
  Serial.print(PID_value/2.55);
  Serial.print("\t");
  Serial.print(hum);
  Serial.print("\t");
  Serial.print(amb_temp);
  Serial.print("\t");
  Serial.print("\n");
  delay(500);
}

/////////////////////////////////////////////////////////////////////////////////
//functions
/////////////////////////////////////////////////////////////////////////////////

double readThermocouple(int CS, int SO, int SCK) {

  uint16_t v;
  pinMode(CS, OUTPUT);
  pinMode(SO, INPUT);
  pinMode(SCK, OUTPUT);
  
  digitalWrite(CS, LOW);
  delay(1);

  // Read in 16 bits,
  //  15    = 0 always
  //  14..2 = 0.25 degree counts MSB First
  //  2     = 1 if thermocouple is open circuit  
  //  1..0  = uninteresting status
  
  v = shiftIn(SO, SCK, MSBFIRST);
  v <<= 8;
  v |= shiftIn(SO, SCK, MSBFIRST);
  
  digitalWrite(CS, HIGH);
  if (v & 0x4) 
  {    
    // Bit 2 indicates if the thermocouple is disconnected
    return NAN;     
  }

  // The lower three bits (0,1,2) are discarded status bits
  v >>= 3;

  // The remaining bits are the number of 0.25 degree (C) counts
  return v*0.25;
}
